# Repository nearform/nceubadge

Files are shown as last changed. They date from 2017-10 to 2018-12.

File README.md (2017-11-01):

# NodeConf EU 2017 Badge

Open Source Hardware Board 

### All documentation including the Getting Started Guide and explanations of the sample code in this repo is available on [nodeconfeubadge.org](http://nodeconfeubadge.org)

## Hardware
This is an Open Source Hardware project. Schematics and board design files are available in the /hardware directory

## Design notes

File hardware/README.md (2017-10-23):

Nodeconf EU hardware design files
=================================

The Badge's hardware was designed in [Eagle CAD](https://www.autodesk.com/products/eagle/overview)

You'll find the original design files here, as well as PDF versions of the schematic and board.

Parts
-----

The main components are:

* [MDBT42Q](http://www.raytac.com/download/MDBT42/MDBT42Q%20&%20MDBT42Q-P-Version%20D.pdf) Bluetooth Module (with [nRF52832](https://www.nordicsemi.com/eng/Products/Bluetooth-low-energy/nRF52832) MCU)
* [MCCOG128064B12W-SPR](http://www.farnell.com/datasheets/2151561.pdf) LCD

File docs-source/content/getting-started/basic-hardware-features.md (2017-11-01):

---
title: "Accessing Hardware Features"
weight: 8
date: 2017-10-28T15:30:33+01:00
draft: false
---

This is an Open Source Hardware project. Schematics and board design files are available in the [/hardware directory of the repo](https://github.com/nearform/nceubadge/tree/master/hardware).

The badge uses the same core module as the [Puck.js](https://www.espruino.com/Puck.js) and can run most of the same software. 

Hardware Features include:

* nRF52832 SoC - 64MHz ARM Cortex M4, 64kB RAM, 512kB Flash, running the Espruino stack
* Bluetooth Low Energy
* Powered by a CR2032 battery which can last up to a week depending on what code you are running
* Daylight-readable LCD screen
* 6 input buttons
* Capacitive touch sensors on all 6 corners
* Prototyping area with 8 CPU pins accessible
* Holes for LEDs on all 6 corners
* NFC antenna
* SWD programming pins

### CPU Pins (Vertical line of holes along left hand edge of badge)
You write to or read from a pin with: 

```javascript
digitalWrite(pin, value);
digitalRead(pin);
```

where pin is one of D0, D1, D2, D3, D4, D5, D6, D7, D8 (D0 at top) and value is 0 or 1.

The firmware has some extra API calls and variables for some of the badge features. You can use them as follows:

### Buttons
You can use  

```javascript
digitalWrite(button, value);
digitalRead(button);
``` 

where value is 1 or 0 and button is one of BTNA, BTNB, BTNU, BTND, BTNL, BTNR

### LEDs
If you add LEDs to the corner holes, you can turn them on/off with 

```javascript
digitalWrite(led);
```

where led is one of LED1, LED2, LED3, LED4, LED5, LED6.

### Graphics
In many Espruino examples on the main site, you'll find setup code for different types of screens. That has already been taken care of for you on the badge and you can just access the graphics functions directly. e.g.

```javascript
g.clear();
g.drawString("Hello World",0,0);
g.flip();
``` 

### Capacitive Sense
You can read the capacitance (and hence touch) from the 6 corners using 

```javascript
Badge.capSense(corner);
```

where corner is one of CORNER1, CORNER2, CORNER3, CORNER4, CORNER5, CORNER6. 

### Battery Percentage
You can get an estimate of the battery level by calling 

```javascript
Badge.getBatteryPercentage();
```

It returns an approximate battery percentage remaining based on a normal CR2032 battery (2.8 - 2.2v).

### Set Screen Contrast
You can set the screen contrast with

```javascript
Badge.setContrast(c)
```

where c is a float from 0 to 1

### NFC
You can set the URL that the NFC antenna broadcasts to NFC-capable phones by calling

```javascript
NRF.nfcURL("url")
```

where URL is something like https://www.nearform.com

*NOTE: If your phone is having difficulty picking up the NFC URL, it is likely that the tuning capacitors on your badge need to be changed to different values. Head on over to the Hacking Lounge to get them replaced or be shown how to do it yourself.*

## Advanced: Flashing updated firmware
If you need to flash new firmware to the badge, you must first put it in DFU mode by holding BTNA as you insert the battery and quickly letting go of BTNA. Download the Distribution Packet Zip file containing the new firmware to your phobe and use nRF Toolbox on either [Android](https://play.google.com/store/apps/details?id=no.nordicsemi.android.nrftoolbox&hl=en) or [iOS](https://itunes.apple.com/us/app/nrf-toolbox/id820906058?mt=8) to send it to the badge.

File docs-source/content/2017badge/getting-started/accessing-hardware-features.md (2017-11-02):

---
title: "Accessing Hardware Features"
weight: 8
date: 2017-10-28T15:30:33+01:00
draft: false
---

This is an Open Source Hardware project. Schematics and board design files are available in the [/hardware directory of the repo](https://github.com/nearform/nceubadge/tree/master/hardware).

The badge uses the same core module as the [Puck.js](https://www.espruino.com/Puck.js) and can run most of the same software. 

Hardware Features include:

* nRF52832 SoC - 64MHz ARM Cortex M4, 64kB RAM, 512kB Flash, running the Espruino stack
* Bluetooth Low Energy
* Powered by a CR2032 battery which can last up to a week depending on what code you are running
* Daylight-readable LCD screen
* 6 input buttons
* Capacitive touch sensors on all 6 corners
* Digital I/O on all 6 corners
* Analogue-in on 3 corners
* Prototyping area with 8 CPU pins accessible
* Digital I/O on all 8 pins
* Analogue-in on 4 pins
* Holes for LEDs on all 6 corners
* NFC antenna
* SWD programming pins

### Proto holes and corner holes
You write or read a digital high/low to/from a hole with: 

```javascript
digitalWrite(hole, value);
digitalRead(hole);
```

where hole is one of D0, D1, D2, D3, D4, D5, D6, D7, D8 (D0 at top), CORNER1, CORNER2, CORNER3, CORNER4, CORNER5, CORNER6 and value is 0 or 1.

You read an analogue value from a hole with: 

```javascript
analogRead(hole);
```

where hole is one of D2, D3, D4, D5, CORNER4, CORNER5, CORNER6.

### Buttons
You can use a generic call like 

```javascript
digitalRead(button);
``` 

where button is one of BTNA, BTNB, BTNU, BTND, BTNL, BTNR

or with a Button-specific call 

```javascript
BTNx.read();
``` 

where BTNx is one of BTNA, BTNB, BTNU, BTND, BTNL, BTNR

### LEDs
If you add LEDs to the corner holes, you can turn them on/off with a generic call

```javascript
digitalWrite(led, value);
```

where led is one of LED1, LED2, LED3, LED4, LED5, LED6.

or with an LED-specific call 

```javascript
LEDx.write(value);
```

where LEDx is one of LED1, LED2, LED3, LED4, LED5, LED6 and value is 0 or 1.

### Graphics
In many Espruino examples on the main site, you'll find setup code for different types of screens. That has already been taken care of for you on the badge and you can just access the graphics functions directly. e.g.

```javascript
g.clear();
g.drawString("Hello World",0,0);
g.flip();
``` 

### Capacitive Sense
You can read the capacitance (and hence touch) from the 6 corners using 

```javascript
Badge.capSense(corner);
```

where corner is one of CORNER1, CORNER2, CORNER3, CORNER4, CORNER5, CORNER6. See [note here](/getting-started/using-prototyping-area/#important-note-re-leds-and-touch-sensing) about issue of using sense and LEDs together.

### Battery Percentage
You can get an estimate of the battery level by calling 

```javascript
Badge.getBatteryPercentage();
```

It returns an approximate battery percentage remaining based on a normal CR2032 battery (2.8 - 2.2v).

### Set Screen Contrast
You can set the screen contrast with

```javascript
Badge.setContrast(c)
```

where c is a float from 0 to 1

### NFC
You can set the URL that the NFC antenna broadcasts to NFC-capable phones by calling

```javascript
NRF.nfcURL("url")
```

where URL is something like https://www.nearform.com

## Advanced Only: Flashing updated firmware
If you need to flash new firmware to the badge, you must first put it in DFU mode by holding BTNA as you insert the battery and quickly letting go of BTNA. Download the Distribution Packet Zip file containing the new firmware to your phone and use nRF Toolbox on either [Android](https://play.google.com/store/apps/details?id=no.nordicsemi.android.nrftoolbox&hl=en) or [iOS](https://itunes.apple.com/us/app/nrf-toolbox/id820906058?mt=8) to send it to the badge.

Please only do this if you are sure you need it. By using a stock badge build from the Espruino site, you'll lose the built-in NodeConf EU main.js code and will just have a REPL over Bluetooth on your badge.

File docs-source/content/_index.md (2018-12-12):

# The NodeConf EU 2018 Badge

Welcome!

We hope you are as excited as we are about the badge. We've spent the past few months designing and preparing it for the event.

The blog post announcing the badge is [here](https://www.nearform.com/blog/the-nodeconf-eu-2018-digital-badge-is-here-and-its-fabulous/).

## The Badge

The badge contains a small but powerful Bluetooth LE module running [Espruino](https://www.espruino.com) software, which is a JavaScript interpreter optimised for low-power devices. On this site, we'll explain the basics of using and programming the badge and even how to add hardware to it.

Note that all of the software and hardware for this year's badge will be Open Sourced shortly after NodeConf EU 2018 is over.

## Changing your name on the badge

This was the top request during NodeConf EU so we've made it as easy as possible. Just [go here](https://nearform.github.io/nceubadge2018/namechanger.html) and follow the simple instructions.

## Quick Links

- [GitHub Repo](https://github.com/nearform/nceubadge2018)
- [Espruino Bluetooth Getting Started](http://www.espruino.com/Quick+Start+BLE#pixljs)
- [Espruino Pixl.js info](http://www.espruino.com/Pixl.js)
- [Monday's Bluetooth Workshop](https://gfwilliams.github.io/workshop-nodeconfeu2018/)
- [Returning your badge to normal](#returning-to-standard)
- [The Badge's default firmware](https://github.com/nearform/nceubadge2018/blob/master/js/badge.js)

Please submit PRs for any apps or backlight patterns you created in:

- [Apps](https://github.com/nearform/nceubadge2018/tree/master/apps)
- [Patterns](https://github.com/nearform/nceubadge2018/tree/master/patterns)

To add them to your badge, connect with the IDE then copy and paste
them into the left-hand side of the IDE.

## Getting Started

The badge is based on a [Pixl.js](http://www.espruino.com/Pixl.js), so a
lot of the tutorials and information there still apply.

The button names can be hard to read because of the badge surround, but they
are as follows:

```
  ......                      ......
      ___________________________
BTN1 |                           | BTN2
     |                           |
     |                           |
     |                           |
BTN4 |___________________________| BTN3
                  ::::
```

There is an on/off slider switch on th rear of the badge just by the USB connector
(which is used for charging only).

## Bugs!

- On some of the badges, the vibration caused by the vibration motors during startup can
  cause the LED controller to stop working. If when you power your badge on it _doesn't_ go
  through all the colours of the rainbow, power it on with your thumbs over the vibration motors
  at the bottom left and right of the screen.
- If your badge stops animating while in badge mode, try just pressing a button
  and it should spring back to life (updating the actual Espruino firmware can fix
  this - see [Updating Espruino](#updating-espruino) below).
- When you charge the badge via USB, the on/off switch on the back needs to be
  set to ON (with the sticky-out part nearest the USB connector) or the battery
  won't charge.
- If you're writing bits of code using `require("Storage").write('.boot...')`
  you may eventually get errors about not being able to write (the same can happen
  when trying to change settings). You can solve this by following the
  [Returning your badge to normal](#returning-to-standard) instructions -
  but [Updating Espruino](#updating-espruino) can stop it happening again as well.

## Connecting

To avoid a complete free-for-all, when the badges start with the Nodeconf badge software
they disable the ability to connect to them. To connect, you must do one of:

- Go to the `Make Connectable` menu item
- Power the badge off, and power it on with `BTN2` or `BTN3` held down. The badge
  firmware will be loaded, but your badge will be connectable.
- (Not recommended) Power the badge off, and power it on with `BTN1` held down while the bootloader
  percent bar goes to the end, **then release when told. Do not keep holding the button
  down or all saved badge code will be erased.**. This initialises a self
  test, which will fail (because the board isn't quite a standard Pixl.js). This
  will start your badge without loading any of the badge code.

You can then use the Chrome web Browser on any Windows 10 or Mac OS device
and go to <a href="https://www.espruino.com/ide" target="_blank">espruino.com/ide</a> and you can connect.
You're looking for a device called `Pixl abcd` where `abcd` are the last 4
characters of the MAC address shown on the Badge's screen.

\*If you used Espruino before, ensure that the `Save on Send` option in the
`Communications` part of the Web IDE's settings is set to `To RAM` otherwise
you'll overwrite the badge firmware.\*\*

Check out the notes for Monday's [Bluetooth Workshop](https://gfwilliams.github.io/workshop-nodeconfeu2018/)
for more information.

### Using your own Editor

You can use the Espruino CLI:

```
npm install -g espruino

# abcd = last 4 digits displayed on your badge
espruino -d abcd --config RESET_BEFORE_SEND=false -w filename.js
```

The `-w filename,js` option watches that file for changes, so the connection
to the badge (and REPL) will be maintained and every time you save the file
in your editor it'll automatically upload.

In this case the CLI tool will upload to RAM without resetting the device,
so writing an app like this will allow you to quickly test your code:

```
Badge.apps["My App"] = ()=>{
 // Reset everything on the badge to a known state
 Badge.reset();
 // Display a menu
 Pixl.menu({ "": { "title": "-- A Test --" },
   "LED1 on" : ()=>LED1.write(1),
   "LED1 off" : ()=>LED1.write(0),
   "Back to Badge":Badge.badge
  });
};
// automatically run app for testing
Badge.apps["My App"]();
```

## Returning to Standard

- <a href="https://www.espruino.com/ide/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" target="_blank">Click this link</a> in Chrome
- Change `Badge.NAME = ...` to `["Your", "Name"]` - each array element is a new line
- Connect to your badge (see above)
- If you're having trouble connecting, power your badge on with `BTN1` held down for ~10 seconds (until a message about code being erased is shown) - this will remove all code from the badge and make it connectable - ready for you to re-upload the badge code.
- Optional: Type `require("Storage").eraseAll()` in the left hand side of the IDE. This will remove all data from nonvolatile storage.
- Turn the `Save on Send` option in the `Communications` part of the Web IDE's settings to `Direct To Flash`
- Upload the code
- Return the `Save on Send` option in the `Communications` part of the Web IDE's settings to `To RAM` so you don't accidentally overwrite the code in the future.

You're sorted!

## Stuff to do

On the badge, you have a bunch of stuff you can use. Most of it is available via `NC`
in a global variable created by the badge software. If you're trying to
do things on your own without the badge software, use `var NC = require("nodeconfeu2018");`
first.

### Bluetooth

Check out [the Pixl.js page](http://www.espruino.com/Pixl.js) for examples.

### LED1, LED2

You can turn the LEDs on and off with `digitalWrite(LED1,1)` or `LED1.write(1)`. Use `0` to turn them off.

### RGB lighting

The badge has fancy RGB lighting. There's:

- **LEDs facing up** - Change these with `NC.ledTop([R,G,B])` or `NC.ledTop([])` to turn them off
- **LEDs facing down** - Change these with `NC.ledBottom([R,G,B])` or `NC.ledBottom([])` to turn them off
- **LCD backlight with 4 zones** - Change this with `NC.backlight([B,G,R,B,G,R,B,G,R,B,G,R])` or `NC.backlight([])` to turn them off

In the above code, `B/G/R` are numbers between 0 and 255 and represent Blue, Green and Red.

### Light sensor

LED2 can be used as an ambient light sensor - just use `NC.light()` to get
a reading between 0 and 1.

It will _definitely_ be thrown off by any light from any of the other on-badge LEDs.

### Vibration

You can use the vibration motors just like normal pins on Espruino...

```
// Use VIBL/VIBR for left and right motors

// Motor on
digitalWrite(VIBL,1);
// Motor off
digitalWrite(VIBL,0);
// Pulse motor on for 100ms
digitalPulse(VIBL,1,100);
// Pulse motor 3 times, for 100ms, with 150ms between each pulse
digitalPulse(VIBL,1,[100,150,100,150,100]);

// Or slowly ramp the speed of the motor up and down
var n = 0;
setTimeout(function cb() {
  analogWrite(VIBL,Math.sin(n));
  n+=0.01;
  if (n<Math.PI) setTimeout(cb,20);
  else digitalWrite(VIBL,0);
}, 20);
```

### Sound

The vibration motors can also be used to create (reasonably quiet) sounds.

```
analogWrite(VIBL,0.05,{freq:2000});  // Make sound!
```

There are some very simple examples at http://www.espruino.com/Making+Music
that will work on the vibration motor - just make sure that the second argument
of `analogWrite` (the duty cycle) is low enough that the vibration motor isn't
turning!

### Accelerometer

```
console.log(NC.accel());
// {x,y,z}
```

### Magnetometer

```
console.log(NC.mag());
// {x,y,z}
```

### LiPo

```
NC.getBatteryState()
// { charging:bool, standby:bool}
```

## Extending the badge

You can add your own 'Apps' or LED patterns that will display in the Badge's
memory just by adding them to the `Badge.patterns` or `Badge.apps` arrays.

Normally when you upload code from the right-hand side of the IDE it will reset
the badge (this won't remove saved code, but will stop the badge code from running).
To avoid this, either copy/paste your code from the right-hand side of the IDE
to the left, or disable the `Reset before send` option in the `Communications` part
of the Web IDE's settings.

## Patterns

Just do something like:

```
// LED patterns - each is [callback, period_in_ms]
Badge.patterns.blue=()=>{ var n=0;return [()=>{
  var c = [127,0,0];
  NC.ledTop(c);
  NC.ledBottom(c);
  NC.backlight(c.concat(c,c,c));
},0];};
```

And you can test by running `Badge.pattern("mine")`.

The above example will only be called once because it returns `0` for `period_in_ms`,
but you can easily supply a different value to be called more often:

```
Badge.patterns.green=()=>{ var n=0;return [()=>{
  n+=50;
  if (n>1536)n=0;
  NC.ledTop([0,Math.max(255-Math.abs(n-1024),0),0]);
  NC.ledBottom([0,Math.max(255-Math.abs(n-1384),0),0]);
  NC.backlight([0,Math.max(255-Math.abs(n-640),0),0,
                0,Math.max(255-Math.abs(n-512),0),0,
                0,Math.max(255-Math.abs(n-384),0),0,
                0,Math.max(255-Math.abs(n-256),0),0]);
},50];};
```

50ms is usually a good balance of battery life and smoothness.

## Apps

Just write your app to the `Badge.apps` array:

```
Badge.apps["My App"] = ()=>{
 // Reset everything on the badge to a known state
 Badge.reset();
 // Display a menu
 Pixl.menu({ "": { "title": "-- A Test --" },
   "LED1 on" : ()=>LED1.write(1),
   "LED1 off" : ()=>LED1.write(0),
   "Back to Badge":Badge.badge
  });
};
```

And you can test by running `Badge.apps["My App"]()`

To return to normal badge functionality just call `Badge.badge()` or `Badge.menu()`
to return to the menu.

## Saving...

When you upload code as described above, your function will be loaded
into RAM and will be lost when the badge is reset.

To make it persist, you can write it into a file in the badge's storage
called `.boot0`,`.boot1`,`.boot2` or `.boot3` - each one is executed in
turn on boot so you can have more than one extension at once.

```
require("Storage").write(".boot0",`
Badge=global.Badge||{};
Badge.apps=Badge.apps||{};
Badge.apps["My App"] = ()=>{
 // Reset everything on the badge to a known state
 Badge.reset();
 // Display a menu
 Pixl.menu({ "": { "title": "-- A Test --" },
   "LED1 on" : ()=>LED1.write(1),
   "LED1 off" : ()=>LED1.write(0),
   "Back to Badge":Badge.badge
  });
};
`);
```

You can also do things like overwrite the built-in name,
without having to overwrite the basic badge firmware.

```
require("Storage").write(".boot1",`
Badge=global.Badge||{};
Badge.NAME=["Hello","World"];
`);
```

## Common Pitfalls

- If you get `Badge not found` errors while trying to upload an app from the right hand side, it'll be because you're uploading with the `Reset before send` option turned on in the IDE settings (it should be turned off)
- `reset()` (or 'reset before send) removes all JS code from the badge's RAM (including the `Badge` object) - it can be handy if you want to have full control of everything on the badge. To get back, see the next point...
- If you want to get your badge firmware back out of flash memory _without_ power cycling your badge, just type `load()` in the left-hand side of the IDE
- Calling `Badge.menu()` will bring the Badge's menu back up - `Badge.badge()` goes back to displaying the badge. If you want a button in the app to bring you back to the menu, you can just call: `setWatch(Badge.menu, BTN1);`
- `Badge.reset()` attempts to reset the badge's state (removing watches and intervals) - it's an idea to stick this as the first line in your app to make sure you start from a known state each time.

## Soldering Stuff

There are some special GPIO connectors on the badge. These can be accessed with
commands like `digitalWrite(D10,1)` or `analogRead(A0)`.

- `J2` (Top Left) contains (left to right) `GND`,`D10`,`D11`,`D12`,`D13` and `3.3v`
- `J1` (Top Right) contains (left to right) `GND`,`A0`,`A1`,`A2`,`A3` and `3.3v`
- `J3` (Bottom center) contains the pinout for an ESP8266 ESP01 module. This can
  also be used for wired serial comms with the badge:

```
GND            NC    NC        D1(Badge TX)
D0(Badge RX)   D9    NC        3.3v
```

### ESP8266 Wiring

Due to a slight mirroring accident, a normal ESP8266 module has to be attached
to the FRONT of the badge, slightly covering the display:

```
  ......                      ......
      ___________________________
BTN1 |                           | BTN2
     |                           |
     |            ____           |
     |           |    |          |
BTN4 |___________|    |__________| BTN3
                 |::::|
                  ----
```

However by removing the ESP01's pins and soldering them on the other side of the
module, you can fit the ESP01 to the rear of the badge very tidily.

Once soldered you can access the internet as follows:

```
var WIFI_NAME = "...";
var WIFI_PASS = "...";
D9.set(); // power on
Serial1.setup(115200,{rx:D0,tx:D1});
var wifi = require("ESP8266WiFi_0v25").connect(Serial1, function(err) {
  if (err) throw err;
  console.log("Connecting to WiFi");
  wifi.connect(WIFI_NAME, WIFI_PASS, function(err) {
    if (err) throw err;
    console.log("Connected");
    // Now you can do something, like an HTTP request
    require("http").get("http://www.pur3.co.uk/hello.txt", function(res) {
      console.log("Response: ",res);
      res.on('data', function(d) {
        console.log("--->"+d);
      });
    });
  });
});
```

Check out [http://www.espruino.com/Internet](Espruino's page on Internet stuff)
for more info.

## Updating Espruino

The badges came with Espruino v2.00, but there have [been a few changes](https://github.com/espruino/Espruino/blob/master/ChangeLog)
to Espruino since then that have fixed:

- The badge pausing issue (caused by high Bluetooth LE traffic when scanning)
- Filesystem issues when repeatedly calling `require("Storage").write`
- Other issues

To update Espruino, just [follow the Pixl.js instructions here](http://www.espruino.com/Pixl.js#firmware-updates)
with the 'Cutting edge' build linked from [the firmware download page](http://www.espruino.com/Download#pixljs).

This'll take a few minutes, and you then need to follow the steps for [Returning your badge to normal](#returning-to-standard) - so if you're fine with everything as it is, we'd recommend that you keep version 2.00 for now.

## Changing your name on the badge in the Web IDE

This was the top request during NodeConf EU so we've made it as easy as possible. To update the name displayed by the badge, do the following:

- On the badge, press the top left button, then select "Make Connectable" from the menu and note the last four hex digits of the address of the badge
- <a href="https://www.espruino.com/ide/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" target="_blank">Click this link</a> in Chrome to open the Online IDE with the correct code
- In that code, edit the two fields "Bob" and "Loblaw" to whatever you need.
- Click the yellow Connect button in the top left corner of the IDE
- Click "Web Bluetooth" in the pop-up
- Click your device name
- Once connected, click the "Send to Espruino" button in the middle of the IDE
- Reboot your badge and you'll see the new name

## 2017 Badge

The old docs for the 2017 badge can be found in [Getting Started](/2017badge/getting-started/) and [challenges](/2017badge/challenges/).

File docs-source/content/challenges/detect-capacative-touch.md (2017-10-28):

---
title: "Detect Capacitive Touch"
weight: 3
date: 2017-10-28T10:29:15+01:00
draft: false
---
### Challenge 3

Detect the application and removal of your hand from the capacative sensors on the corners of the badge.

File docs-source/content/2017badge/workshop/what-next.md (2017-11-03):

---
title: "What next?"
weight: 9
date: 2017-11-03T09:45:33+01:00
draft: false
---

What about:

* Putting LEDs around the corners and using those to show the correct 
patterns. However, due to the way the capacitive sense and LEDs are shared,
you'll only be able to use White and Blue LEDs, not any of the coloured
ones!
* Getting rid of all the callbacks. I've been super lazy - you could probably
tidy things up a lot more using Promises.
* Make a much better game.
* Use the Bluetooth to connect to another Badge and control it
* Interface with a Web Bluetooth Website
* Make a multiplayer game!

## Other info

There's loads of info to help online.. Check out:

* http://nodeconfeubadge.org/challenges/
* The Puck.js tutorials - the badge is basically a Puck.js: http://www.espruino.com/Puck.js#tutorials
* The search box on the Espruino site: http://www.espruino.com/Search
* The Espruino function reference: http://www.espruino.com/Reference
* All the rest of Espruino's tutorials - http://www.espruino.com/Tutorials
* The forum! http://forum.espruino.com/ (it's also sometimes worth
Googling `site:forum.espruino.com your_search_term` as the forum's
search isn't the best).

## Bluetooth

We didn't cover Bluetooth at all here! There's a super-quick intro to
BLE on Espruino here: http://www.espruino.com/About+Bluetooth+LE

And there's a tutorial on how to get up and running with Web Bluetooth
and Espruino here: http://www.espruino.com/Puck.js+Web+Bluetooth

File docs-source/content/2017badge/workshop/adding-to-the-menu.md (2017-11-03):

---
title: "Adding to your Badge's menu"
weight: 10
date: 2017-11-03T09:45:33+01:00
draft: false
---

Next we're going to add the game we just made as a menu item inside
the existing badge software.

Wrap everything you've done into the following function on the right-hand
side of the IDE.

```
Badge.apps["Simon Game"] = function() {
  Badge.reset();
  setWatch(Badge.menu, BTNB, { repeat: 1, debounce: 50, edge: "rising" });
  
  // Your code
};
```

Now we need to get the badge back doing badgey stuff. disconnect the IDE 
from your badge, and pull the battery gently away from the PCB with a 
fingernail. When the display flickers off, let go and your badge will 
restart with the old code on it.

Now do the Konami code again - `UUDDLRLRBA`, go to `Make Connectable`,
and connect with the Web IDE. Simply **Copy & Paste** your code from the
right-hand side over to the left, **don't Upload**. If you upload, it'll
reset the device and upload your code as it did before.

This way, your code will now be loaded into RAM alongside the Badge's code.

Disconnect the IDE and press the `A` button on the badge to exit the
`Connectable` state. You'll now have a new menu item at the end of the list 
called `Simon Game`, and when you choose it it'll run your game!

**Note:** We've totally filled up the flash memory with all the Badge stuff,
so you won't be able to save your game like this and if you reset your badge
by removing the battery it'll disappear.

Instead, you'd have to upload and save just the game as was done in the
last step.

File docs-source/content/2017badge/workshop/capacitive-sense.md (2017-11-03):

---
title: "Capacitive Sense"
weight: 3
date: 2017-11-03T09:45:33+01:00
draft: false
---

To detect a press, we want to use the capacitive sense functionality on the badge.
Type `Badge.capSense(1)` on the left-hand side of the IDE. You can use tab-complete
to help you. You should get a number displayed in the region of about `10,000` - this
value depends on the capacitance on that corner of the badge.

Press your finger on the corner marked `1` and try again (up arrow, then enter)
- you should see a much higher value - probably over `100,000`.

We can read all 6 corners using ES6 arrow functions and `map`:

```
[1,2,3,4,5,6].map(c=>Badge.capSense(c))
```

Note that not all corners are identical - for instance the corner nearest the
Bluetooth module (corner 3) will probably read a bit less, because there's less
wire.

It's easy enough for us to just threshold the capacitance values to
return an array of boolean values. You can use up-arrow and left to
move the cursor and edit the last line (or even the mouse), **but
you need to get the cursor on the end of the line before you
hit enter or it'll create a newline rather than executing**:

```
[1,2,3,4,5,6].map(c=>Badge.capSense(c)>20000)
```

So at this point it'd be nice to use the display to show our values...

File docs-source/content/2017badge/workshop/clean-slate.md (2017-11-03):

---
title: "Clean Slate"
weight: 2
date: 2017-11-03T09:45:33+01:00
draft: false
---

Clear everything out of the right-hand side of the IDE window, and click the
'Upload' button in the middle of the screen (a picture of a chip and an up-arrow).

The Badge should now just display the 'Espruino' logo - this is what gets
displayed when no code has been loaded.

Don't worry though **- this hasn't overwritten what was on the badge before.**
That code is in Flash memory, and uploading an empty file has left the contents
 of RAM empty, while the Flash memory has stayed the same. Removing the battery
 and re-inserting (or flicking it away with your finger) will make the badge
 reload everything.

**Note:** If you have `Save on Send` set in the options, or type `save()`
then it *will* blow away the contents of the badge.

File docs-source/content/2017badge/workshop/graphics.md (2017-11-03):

---
title: "Graphics"
weight: 4
date: 2017-11-03T09:45:33+01:00
draft: false
---

The badge exposes the LCD via a built-in variable called `g`. This has 
a bunch of methods such as `drawLine` or `drawString` that can be accessed
(http://www.espruino.com/Graphics) however each command acts on an internal
memory buffer. To update the display itself you need to call `g.flip()`.

Try entering the following code on the left-hand side:

```
g.clear();
g.drawString("Hello World!");
g.flip();
```

The badge should now display the obvious 'Hello World'!

But what if we want to display our capacitance data? Enter the following
on the *left-hand side*.

```
function plotCap() {
  g.clear();  
  var caps = [1,2,3,4,5,6].map(c=>Badge.capSense(c));
  caps.forEach(
    (cap,x) => g.fillRect(x*21,64,(x+1)*21, 64-cap/1000)
  );
  g.flip();
}
setInterval(plotCap,50)
```

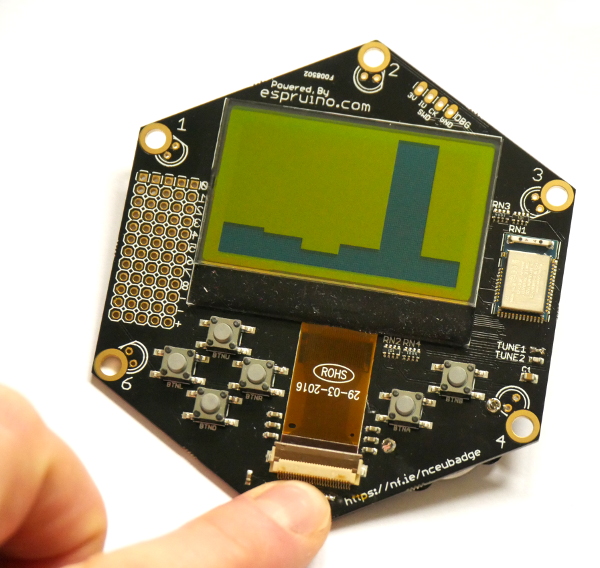
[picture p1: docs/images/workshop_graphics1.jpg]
Plot capacitance


**Note:** This uses a whole bunch of battery power because of polling the
capacitive sense as well as updating the screen, and if left this way
could run the Badge's battery down in a few hours. When using the buttons
rather than capacitive sense, the hardware itself can detect the change
in the wire's voltage while the processor is asleep - you do that
using `setWatch` - which is super power efficient.

This is just displaying a few bars, but it would make more sense to display
the status on a hexagon that matched the badge itself:

```
function plotBadge(presses) {
  g.clear();    
  // function to work out each corner's coordinates
  function corner(c,r) {
    var a = (c-2)*Math.PI/3;
    return [64+Math.sin(a)*40*r, 32-Math.cos(a)*30*r];
  }
  // draw a hexagon - a line to each corner in turn
  g.moveTo.apply(g,corner(6,1));
  [1,2,3,4,5,6].forEach(c=>g.lineTo.apply(g,corner(c,1)));
  // Draw a circle where pressed
  presses.forEach((hit,c) => {
    if (!hit) return;
    var coords = corner(c+1,0.8);
    g.fillCircle(coords[0],coords[1],5);
  });
  g.flip();
}

function plotCap() {  
  var caps = [1,2,3,4,5,6].map(c=>Badge.capSense(c)>20000);
  plotBadge(caps);
}
```

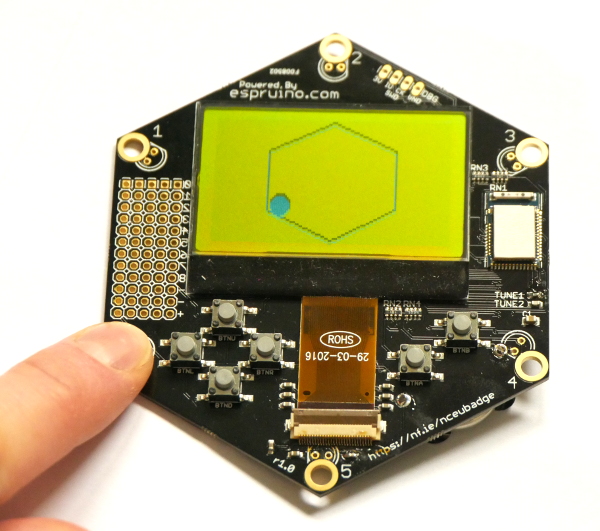
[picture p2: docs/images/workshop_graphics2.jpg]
Plot corners


We're using a separate `plotBadge` function here so we can use it
later to output the pattern we want the user to enter.

**Note:** because we're entering this on the left-hand side we
already have the interval from the last code we entered - just
re-entering `plotCap` will replace the old one and the code will magically
start working.

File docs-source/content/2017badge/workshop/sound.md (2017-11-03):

---
title: "Sound"
weight: 5
date: 2017-11-03T09:45:33+01:00
draft: false
---

It'd be nice if our game made some sounds. There's no speaker built into the
badge, so we're going to add one.

Get one of the gold coloured discs from the hacking bench - these are piezo
speakers of the type you'd find in digital watches.

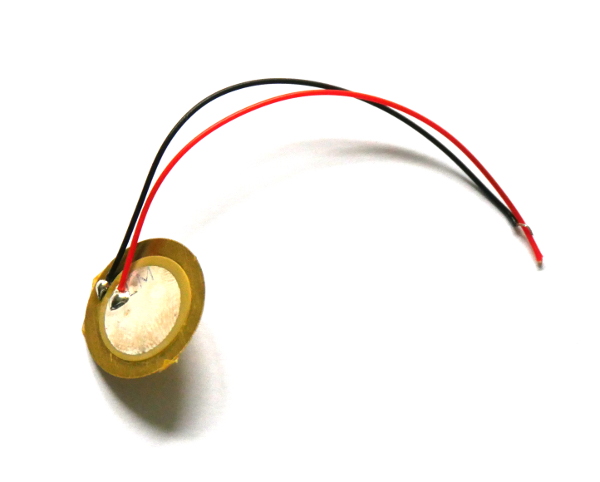
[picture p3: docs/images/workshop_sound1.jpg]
Piezo


Use the wire strippers and try and strip around 2cm of insulation off each of
the two wires. By careful - maybe try stripping 1cm first, then another cm,
as the wire is really delicate.

Twist each bit of wire so it makes a nice braid, then poke each through the
holes on the edge of the board marked 0 and 1 (the order doesn't matter) and
twist them around tightly as below. 0 and 1 correspond to pins `D0` and `D1`.

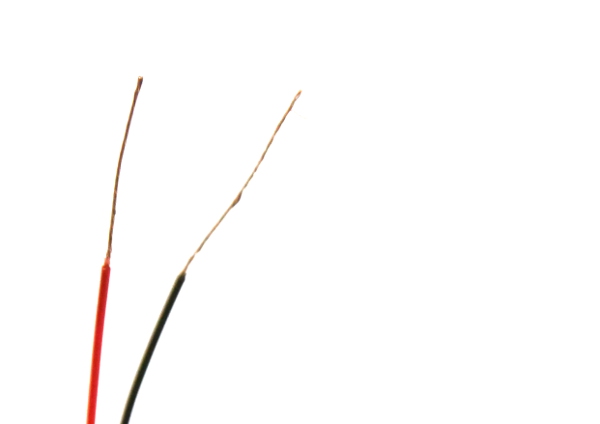
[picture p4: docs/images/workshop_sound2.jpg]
Piezo wires


**Note:** You're welcome to solder the speaker on if you want to - it's just
quick and reversible to twist.

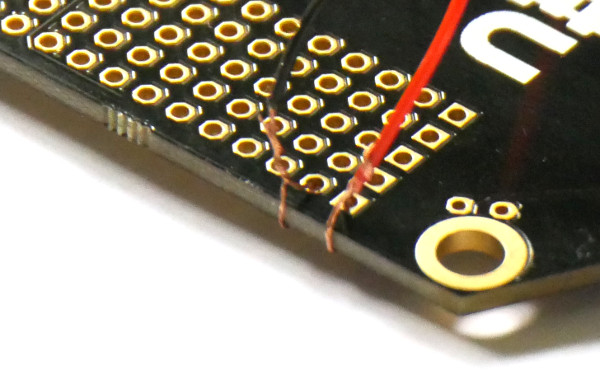
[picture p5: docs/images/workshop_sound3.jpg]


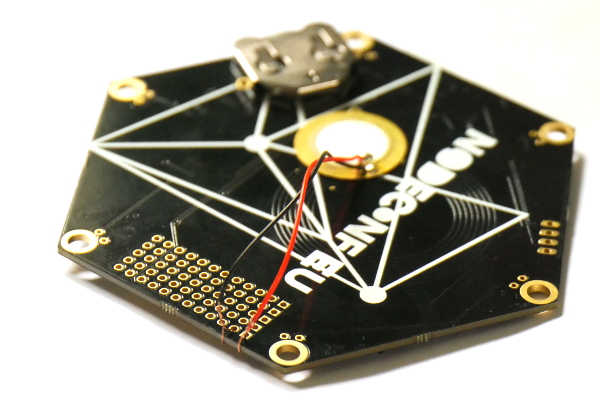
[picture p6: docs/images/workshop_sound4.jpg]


Now get a bit of double-sided tape and tape the speaker to the back of your 
badge. It makes it louder if it can vibrate something else.

Now you can test it - in the left-hand side of the IDE type:

```
digitalWrite(D0,0)
```

This sets pin `D0` to be connected to ground.

```
analogWrite(D1,0.5,{freq:1000})
```

This puts a 1kHz frequency on pin D1, and you should be able to hear
a really annoying high pitched beep.

Type this to turn it off:

```
digitalWrite(D1,0)
```

So now all we need is a handy function to do timed beeps:

```
function beep(freq, time, callback) {
  digitalWrite(D0,0);
  analogWrite(D1,0.5,{freq:freq});
  setTimeout(function() {
    digitalWrite(D1,0);
    if (callback) callback();
  }, time);
}
```

Which you can try with:

```
beep(700,1000)
```

For a 700Hz beep for 1 second, and so on...

For our Simon game we need a different beep for each corner, so let's make
a function for that.

```
function beepForCorner(corner, time) {
  var pitches = ["no_corner_0",
    500,
    600,
    700,
    800,
    900,
    1000
  ];
  beep(pitches[corner], time);
}
```

Which you can use with `beepForCorner(2,1000)`.

These pitches are totally un-musical, but if you were so inclined you could
look up some more pleasing notes at https://pages.mtu.edu/~suits/notefreqs.html
and use those frequencies instead.

## It's too quiet!

(optional!)

Unfortunately the piezo speakers we're using aren't really meant to run
off a voltage as low as we have on the badge (3V).

We're driving them with a square wave between 0V and 3V while `D0` is at 0V, 
so the total swing in voltage is 0V.

However, if we could make `D0` go to 3V when `D1` was at 0V and vice-versa,
we'd be able to get double the voltage swing - 6V!

The following code uses the NRF52LL library, which has a bit more info
in it: http://www.espruino.com/NRF52LL

Basically there's nothing built in to the Espruino interpreter to handle this,
so we have to set up the hardware that's on the chip ourself - which is
pretty low-level.

```

function beep(freq, time, callback) {
  var ll = require("NRF52LL");
  // set up D0 and D1 as outputs
  digitalWrite(D0,0);
  digitalWrite(D1,0);
  // create two 'toggle' tasks, one for each pin
  var t0 = ll.gpiote(6, {type:"task",pin:D0,lo2hi:1,hi2lo:1,initialState:0});
  var t1 = ll.gpiote(7, {type:"task",pin:D1,lo2hi:1,hi2lo:1,initialState:1});
  // create a timer that counts up to a value depending on the frequency
  var tmr = ll.timer(3,{cc:[500000/freq],cc0clear:1});
  // use two PPI to trigger toggle events
  ll.ppiEnable(6, tmr.eCompare[0], t0.tOut);
  ll.ppiEnable(7, tmr.eCompare[0], t1.tOut);
  // Manually trigger a task to start the timer
  poke32(tmr.tClear,1);
  poke32(tmr.tStart,1);
  setTimeout(function() {
    poke32(tmr.tStop,1);
    ll.ppiDisable(6);
    ll.ppiDisable(7);
    if (callback) callback();
  }, time);
}
```

This code uses a library that's dynamically loaded in by the IDE, so you'll
have to use the code on the **right-hand side of the IDE** and use the `Upload` button
in order to have it work correctly.

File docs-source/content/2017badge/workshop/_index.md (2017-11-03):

---
title: "Workshop"
weight: 3
chapter: true
date: 2017-11-02T10:29:15+01:00
draft: false
---

# Monday's Workshop

We're going to make a 6-cornered ['Simon' game](https://en.wikipedia.org/wiki/Simon_(game)),
 using capacitive sense on each corner of the badge instead of the usual 4 cornered game.

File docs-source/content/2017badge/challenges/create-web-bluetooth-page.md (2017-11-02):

---
title: "Create a Web Bluetooth Page"
weight: 12
date: 2017-10-28T10:29:15+01:00
draft: false
---
### Challenge 12

Implement a webpage that uses Web Bluetooth with the Puck.js library. Start simple and turn on/off an LED on your badge.

Eventually make it retrieve your last tweet from the Twitter API and then display it on the badge screen.

Lots of information about web Bluetooth and Espruino [here](https://www.espruino.com/Puck.js+Web+Bluetooth).

#### Add a menu via Web Bluetooth
You can really see the power of Web Bluetooth and Espruino by trying something like this:

```javascript
Puck.write(`
Badge.apps["My Foobar"] = function() {
  Badge.reset();
  // my stuff
  // when done, call Badge.menu
  // eg. setWatch(Badge.menu, BTNB, { repeat: 1, debounce: 50, edge: "rising" });
};
`);
```
Create code based on the above in a webpage and host it on GitHub Pages. Write it so that anyone can go to the page, click a button and add the app to their badge.

Note however that if you use any of Espruino's modules, you'll have to run it through the CLI first to output a JS file that also contains the modules.

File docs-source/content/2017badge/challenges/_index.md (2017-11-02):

---
title: "Challenges"
weight: 2
chapter: true
date: 2017-10-28T10:29:15+01:00
draft: false
---

# Try all of these challenges!
You'll start with Hello World and hopefully by Wednesday you'll have a giant P2P badge network running.

Try combining multiple challenges into one codebase.

1. Hello World on screen
2. Detect Button press
3. Detect capacitive touch
4. Add LEDs and flash them
5. Add a Buzzer/Speaker and play music
6. Implement your own on-screen menu
7. Broadcast a different NFC URL
8. Broadcast an Eddystone and iBeacon message
9. Use Noble and Node.js on your laptop to read the beacon data  
10. Turn the Badge into HID buttons for your PC.
11. Create and display your own images
12. Implement Web Bluetooth with the Puck.js library
13. Detect movement with a PIR sensor
14. Connect to a BLE LED Lightbulb
15. Connect to a BLE LED Strip
16. Communicate with another badge
17. Communicate with some other Bluetooth devices
18. Implement DAT protocol on Espruino

### The Grand Challenge
Don't forget [the grand challenge](/#the-grand-challenge)!

### Advanced tools
There are several mobile apps from Nordic Semiconductor that you may find useful in any challenges that use Bluetooth. nRF toolbox can also be used to update the badges firmware or re-flash a badge that you have messed up.

#### Android
* [nRF Connect](https://play.google.com/store/apps/details?id=no.nordicsemi.android.mcp&hl=en)
* [nRF Toolbox](https://play.google.com/store/apps/details?id=no.nordicsemi.android.nrftoolbox&hl=en)

#### iOS
* [nRF Connect](https://itunes.apple.com/us/app/nrf-connect/id1054362403?mt=8)
* [nRF Toolbox](https://itunes.apple.com/us/app/nrf-toolbox/id820906058?mt=8)

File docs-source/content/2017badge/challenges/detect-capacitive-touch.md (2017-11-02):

---
title: "Detect Capacitive Touch"
weight: 3
date: 2017-10-28T10:29:15+01:00
draft: false
---
### Challenge 3

It's very easy to read a capacitance value from the 6 lanyard holes in the badge. Experiment with the code and how the badge responds to touch. Then come up with a use for it. 

See the [getting started area](/getting-started/basic-hardware-features/) for the relevant API call.

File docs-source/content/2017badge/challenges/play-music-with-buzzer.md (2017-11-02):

---
title: "Play Music with Buzzer"
weight: 5
date: 2017-10-28T10:29:15+01:00
draft: false
---
### Challenge 5

We have lots of buzzers at the Hacking Station. You just have to solder the red wire to one of the D0-D6 holes on the edge of the badge and the black wire to one of the Ground (-) holes.

Then impress everyone with your groovy tunes using the [APIs here](https://www.espruino.com/Making+Music).

Note: Gordon is working on a variation of this that uses two digital pins and doubles the output volume.

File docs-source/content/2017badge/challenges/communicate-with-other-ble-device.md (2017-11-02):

---
title: "Communicate with another Device"
weight: 17
date: 2017-10-28T10:29:15+01:00
draft: false
---
### Challenge 17

If you can get your hands on some other BLE device like a Garmin, Fitbit or Milestone, see if you can figure out the protocol.

If you figure it out, write a blogpost about it!

Some of these devices may require registering on the relevant developer sites. However we may have some other Bluetooth devices on the Hacking Table which are easier to communicate with.

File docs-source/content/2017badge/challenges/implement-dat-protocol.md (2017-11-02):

---
title: "Implement Dat Protocol"
weight: 18
date: 2017-10-28T10:29:15+01:00
draft: false
---
### Challenge 18

We're kidding.

Or are we?

What sort of P2P messaging system could be created by all the badges at the event? Without burning through the battery in 5 minutes.

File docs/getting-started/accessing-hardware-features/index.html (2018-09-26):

> Getting Started > Accessing Hardware Features

# Accessing Hardware Features

This is an Open Source Hardware project. Schematics and board design files are available in the /hardware directory of the repo (https://github.com/nearform/nceubadge/tree/master/hardware).

The badge uses the same core module as the Puck.js (https://www.espruino.com/Puck.js) and can run most of the same software.

Hardware Features include:

- nRF52832 SoC - 64MHz ARM Cortex M4, 64kB RAM, 512kB Flash, running the Espruino stack
- Bluetooth Low Energy
- Powered by a CR2032 battery which can last up to a week depending on what code you are running
- Daylight-readable LCD screen
- 6 input buttons
- Capacitive touch sensors on all 6 corners
- Digital I/O on all 6 corners
- Analogue-in on 3 corners
- Prototyping area with 8 CPU pins accessible
- Digital I/O on all 8 pins
- Analogue-in on 4 pins
- Holes for LEDs on all 6 corners
- NFC antenna
- SWD programming pins

### Proto holes and corner holes

You write or read a digital high/low to/from a hole with:

digitalWrite(hole, value);
digitalRead(hole);

where hole is one of D0, D1, D2, D3, D4, D5, D6, D7, D8 (D0 at top), CORNER1, CORNER2, CORNER3, CORNER4, CORNER5, CORNER6 and value is 0 or 1.

You read an analogue value from a hole with:

analogRead(hole);

where hole is one of D2, D3, D4, D5, CORNER4, CORNER5, CORNER6.

### Buttons

You can use a generic call like

digitalRead(button);

where button is one of BTNA, BTNB, BTNU, BTND, BTNL, BTNR

or with a Button-specific call

BTNx.read();

where BTNx is one of BTNA, BTNB, BTNU, BTND, BTNL, BTNR

### LEDs

If you add LEDs to the corner holes, you can turn them on/off with a generic call

digitalWrite(led, value);

where led is one of LED1, LED2, LED3, LED4, LED5, LED6.

or with an LED-specific call

LEDx.write(value);

where LEDx is one of LED1, LED2, LED3, LED4, LED5, LED6 and value is 0 or 1.

### Graphics

In many Espruino examples on the main site, you’ll find setup code for different types of screens. That has already been taken care of for you on the badge and you can just access the graphics functions directly. e.g.

g.clear();
g.drawString("Hello World",0,0);
g.flip();

### Capacitive Sense

You can read the capacitance (and hence touch) from the 6 corners using

Badge.capSense(corner);

where corner is one of CORNER1, CORNER2, CORNER3, CORNER4, CORNER5, CORNER6. See note here about issue of using sense and LEDs together.

### Battery Percentage

You can get an estimate of the battery level by calling

Badge.getBatteryPercentage();

It returns an approximate battery percentage remaining based on a normal CR2032 battery (2.8 - 2.2v).

### Set Screen Contrast

You can set the screen contrast with

Badge.setContrast(c)

where c is a float from 0 to 1

### NFC

You can set the URL that the NFC antenna broadcasts to NFC-capable phones by calling

NRF.nfcURL("url")

where URL is something like https://www.nearform.com

## Advanced Only: Flashing updated firmware

If you need to flash new firmware to the badge, you must first put it in DFU mode by holding BTNA as you insert the battery and quickly letting go of BTNA. Download the Distribution Packet Zip file containing the new firmware to your phone and use nRF Toolbox on either Android (https://play.google.com/store/apps/details?id=no.nordicsemi.android.nrftoolbox&hl=en) or iOS (https://itunes.apple.com/us/app/nrf-toolbox/id820906058?mt=8) to send it to the badge.

Please only do this if you are sure you need it. By using a stock badge build from the Espruino site, you’ll lose the built-in NodeConf EU main.js code and will just have a REPL over Bluetooth on your badge.

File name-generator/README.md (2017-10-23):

# name-generator

This tool prompts for a NodeConf EU attendee's firstname/lastname and then generates base64 image data for saving on the NCEU badge.

It scales each person's name to make best use of the screen

Copyright nearForm and Conor O'Neill 2017 conor@conoroneill.com
Apache License Version 2.0

Usage (Mac only for the moment):

Install [Node.js](https://nodejs.org/en/download/current/) and then:

```
git clone https://github.com/nearform/nceubadge
cd nceubadge/name-generator

# Mac OS
brew install openssl imagemagick pkg-config cairo libpng jpeg giflib
# Debian/Ubuntu Linux
sudo apt-get install imagemagick pkg-config libcairo2-dev libpng-dev libjpeg-dev libgif-dev

npm install
```

Then run the tool just with

```
node name-generator.js
```

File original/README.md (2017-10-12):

Original Badge Code
=====================

As they come, the badges are flashed with the standard Espruino HEXBADGE 
firmware. *Then* the espruino CLI is used to take a custom HEX file based
on `main.js` which is written it direct to flash.

This is as if `E.setBootCode` was called with the badge's code. The bonus
is that everything can be executed from Flash - freeing up LOADS of RAM.

```
# Install CLI
npm install -g espruino

# create hex file from CLI
espruino --board HEXBADGE main.js -ohex main.hex

# optional flash of hexbadge firmware
nrfjprog --family NRF52 --clockspeed 50000 --program espruino_1v94.159_hexbadge.hex --chiperase --reset
# erase saved code area
nrfjprog --family NRF52 --clockspeed 50000 --erasepage 0x71000-0x76000
# Actually program file
nrfjprog --family NRF52 --clockspeed 50000 --program main.hex --reset
```

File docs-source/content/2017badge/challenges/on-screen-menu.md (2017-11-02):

---
title: "On-Screen Menu"
weight: 6
date: 2017-10-28T10:29:15+01:00
draft: false
---
### Challenge 6

If you implement an on-screen menu with up-down-left-right-select then you could have lots of your challenges on the badge at the same time and demo them to people. Have a look at the [github repo](https://github.com/nearform/nceubadge/) for the sample code. 

#### Add to the existing menu 
You can also try the following: 

* Turn off 'Reset Before Send' in the Web IDE options
* Write your code a bit like this:

```javascript
Badge.apps["My Foobar"] = function() {
  Badge.reset();
  // my stuff
  // when done, call Badge.menu
  // eg. setWatch(Badge.menu, BTNB, { repeat: 1, debounce: 50, edge: "rising" });
};
```

* Upload or copy/paste that code 
* It will appear in the apps list on the badge's menu
* You can't save, but it'll persist until you reset the badge

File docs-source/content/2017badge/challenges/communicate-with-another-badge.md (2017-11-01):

---
title: "Communicate with another Badge"
weight: 16
date: 2017-10-28T10:29:15+01:00
draft: false
---
### Challenge 16

This is another advanced challenge. We recommend starting with the [instructions here](https://www.espruino.com/Puck.js+Controlling+Other+Pucks) and then decide if you want to continue.

Also consider the new [BLE mesh networking standard](http://forum.espruino.com/conversations/308148/) which is currently not supported on Espruino but would make for an impressive community contribution.

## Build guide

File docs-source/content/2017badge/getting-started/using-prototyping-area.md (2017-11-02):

---
title: "Using the prototyping area and corners"
weight: 9
date: 2017-10-28T15:30:33+01:00
draft: false
---

You can add whatever hardware you like to the prototyping area. It's where you'll be connecting extra LEDs, buzzers etc. The column of holes along the board's left edge are connected to pins D0 to D8, Ground and Power. However all of the other holes in that grid are unconnected and can be used to attach your components together.

As always, the [Espruino web-site](https://www.espruino.com/) has lots more info and examples.

## Hole behaviour
The edge holes and the corner holes each have slightly different capabilities.

### Prototype holes

* 0 - Digital I/O Only
* 1 - Digital I/O Only
* 2 - Digital I/O and Analogue-in (ADC)
* 3 - Digital I/O and Analogue-in (ADC)
* 4 - Digital I/O and Analogue-in (ADC)
* 5 - Digital I/O and Analogue-in (ADC)
* 6 - Digital I/O Only
* 7 - Digital I/O and Serial TX
* 8 - Digital I/O and Serial RX
 
### Corner holes

* 1 - Digital I/O Only
* 2 - Digital I/O Only
* 3 - Digital I/O Only
* 4 - Digital I/O and Analogue-in (ADC)
* 5 - Digital I/O and Analogue-in (ADC)
* 6 - Digital I/O and Analogue-in (ADC)

## Important note re LEDs and touch sensing
As LEDn == CORNERn, adding most LEDs to a corner will prevent capacitive sense functioning on that corner. White and blue LEDs will probably work but not other colours.

## Board layout
This shows the basic board layout:

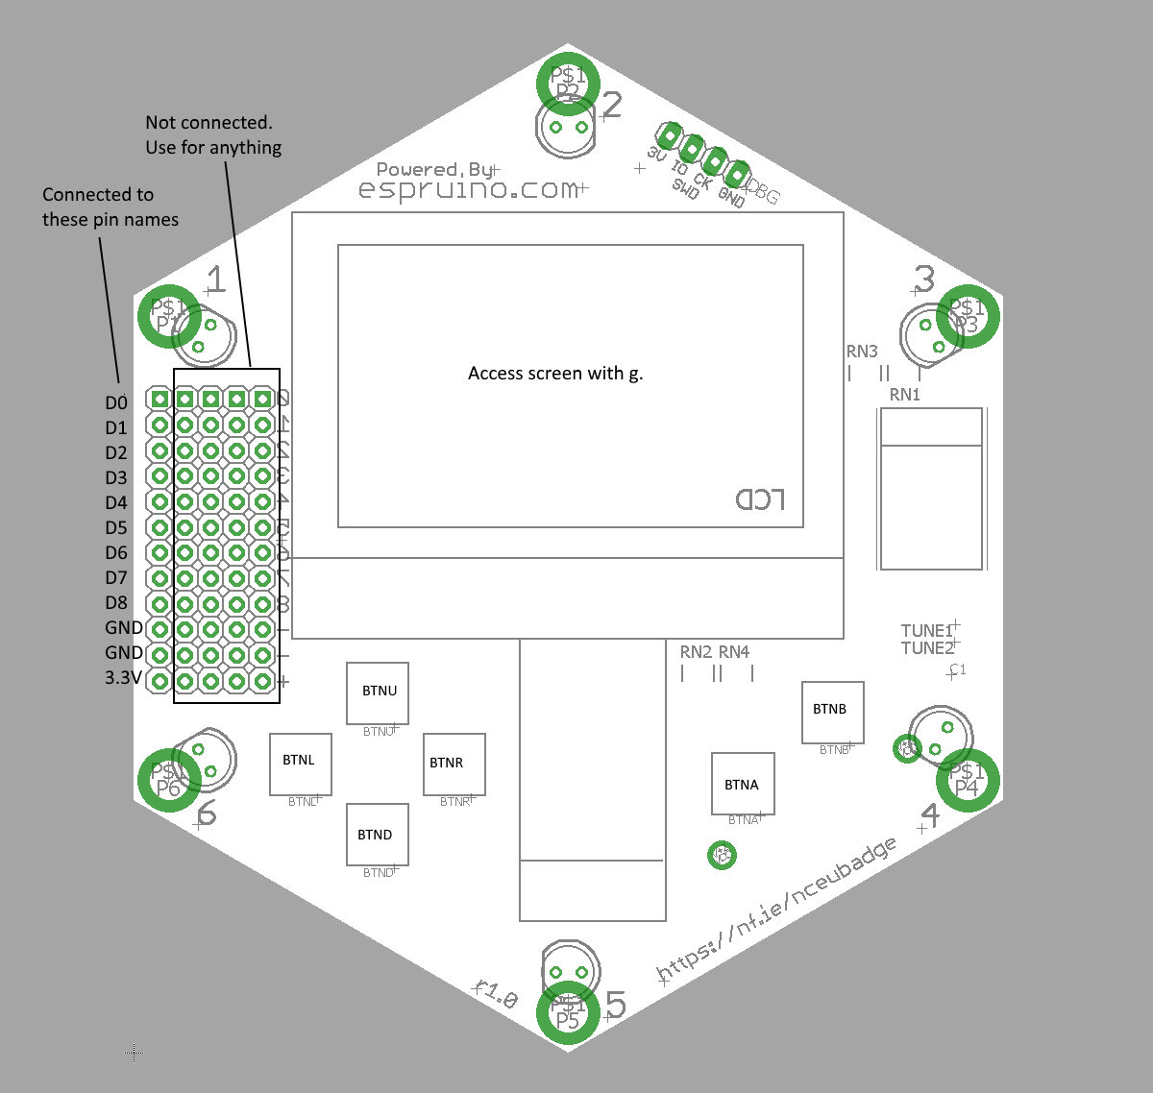
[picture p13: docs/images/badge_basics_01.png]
Board basics


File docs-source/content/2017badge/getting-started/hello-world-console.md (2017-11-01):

---
title: "Hello World on the Console"
weight: 6
date: 2017-10-28T15:30:33+01:00
draft: false
---

Of course we start with Hello World. Follow the [connection instructions](/getting-started/connecting-to-the-badge/), then click on the left hand side of the IDE and type:

```
console.log("Hello World");
```

Now stop and think for a minute about what just happened there in terms of communications flow.

You should try out other aspects of the Web IDE. It has full auto-complete in the REPL window including Button/LED names and functions.

You could also try the built-in Blockly graphical editor which is very similar to Scratch.

Any Espruino code you find here or elsewhere online can be pasted into the editor on the right-hand-side of the IDE and then sent to the badge over Bluetooth for execution. The editor has basic parsing and can flag common errors.

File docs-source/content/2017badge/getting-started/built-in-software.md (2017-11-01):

---
title: "Built-in Software"
weight: 2
date: 2017-10-28T15:30:33+01:00
draft: false
---

Now that you've unlocked the badge (you'll have to do this any time you remove the battery), you can explore the built in sample apps. Out of the box, your badge has the following:

* Your name pre-flashed into the firmware
* Image display cycling
* Selectable menus
* T-Rex who has escaped the Chrome browser
* Flappy Bird
* The world's most awkward on-board REPL
* Etch-a-sketch

Source code for all of these is of course in the [Github Repo](https://github.com/nearform/nceubadge/). More details on these and other samples are [here](/getting-started/other-code-samples/).

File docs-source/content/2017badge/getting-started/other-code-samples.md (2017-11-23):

---
title: "Other Code Samples"
weight: 7
date: 2017-10-28T15:30:33+01:00
draft: false
---

There are three places you can find code to learn from and use:

* The [Badge repo](https://github.com/nearform/nceubadge)
* The [main Espruino site](https://www.espruino.com/)
* The [Puck.js area](https://www.espruino.com/Puck.js) of the Espruino site

## Badge Repo Code
The pre-installed main.js code is a treasure trove of useful snippets. Note however that it's too big to be uploaded in its entirety via the Web IDE.

* [Pre-installed badge code](https://www.espruino.com/ide/#https://raw.githubusercontent.com/nearform/nceubadge/master/flasher/main.js)

### Games
Relive your original Gameboy, Nokia and video arcade days with the following games :-)

* [Flappy Bird](https://www.espruino.com/ide/#https://raw.githubusercontent.com/nearform/nceubadge/master/flappybird.js)
* [Snake](https://www.espruino.com/ide/#https://raw.githubusercontent.com/nearform/nceubadge/master/snake.js)
* [Simple Mario](https://www.espruino.com/ide/#https://raw.githubusercontent.com/nearform/nceubadge/master/mario.js)
* [Asteroids](https://www.espruino.com/ide/#https://raw.githubusercontent.com/nearform/nceubadge/master/asteroids.js)
* [Click speed counter](https://www.espruino.com/ide/#https://raw.githubusercontent.com/nearform/nceubadge/master/click_counter.js)
* [T-Rex](https://www.espruino.com/ide/#https://raw.githubusercontent.com/nearform/nceubadge/master/trex.js)

### Web Bluetooth
* [Retrieve all images stored on a badge](https://github.com/nearform/nceubadge/blob/master/web_bluetooth/badge_images.html) ([try it](/web_bluetooth/badge_images.html))
* [Take a picture with getUserMedia and put it on the badge](https://github.com/nearform/nceubadge/blob/master/web_bluetooth/badge_photo.html) ([try it](/web_bluetooth/badge_photo.html))
* [Upload an image to the badge badge](https://github.com/nearform/nceubadge/blob/master/web_bluetooth/badge_upload.html) ([try it](/web_bluetooth/badge_upload.html))

### Misc
* Check out the [world's most awkward REPL](https://www.espruino.com/ide/#https://raw.githubusercontent.com/nearform/nceubadge/master/repl.js)

* Learn how to [display a Menu](https://www.espruino.com/ide/#https://raw.githubusercontent.com/nearform/nceubadge/master/menu.js)

* Dazzle everyone with your artistic skills on an [Etch-a-sketch](https://www.espruino.com/ide/#https://raw.githubusercontent.com/nearform/nceubadge/master/sketch.js)

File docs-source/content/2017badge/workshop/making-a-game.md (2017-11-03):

---
title: "Making a Game"
weight: 6
date: 2017-11-03T09:45:33+01:00
draft: false
---

Ok, now we'll need to make two functions:

* A function to output a pattern
* A function to check the player's input against a pattern. 

These will take a simple array of numbers, which is the pattern
to output.

## Left -> Right

We've got enough code that we probably want to start using the
right-hand side of the IDE as a proper editor. No changes will take
effect until you press the `Upload` button, but when you upload it'll
blow away any previous changes you made on the left-hand side.

## Outputting a pattern

We've already got the `plotBadge` function from the Graphics section,
as well as `beepForCorner` from the Sound section. All we need to do
is call them at the right times. Copy `plotBadge` and the `beep` stuff onto
the right-hand side, as well as this - and then click the `Upload` button in
the middle of the screen.

```
// Show the given pattern
function showPattern(pattern, callback) {
  // Nothing left - finish
  if (!pattern.length) return callback();  
  // Shift off the first element - don't use shift as
  // that'd alter the initial array  
  var corner = pattern[0];
  pattern = pattern.slice(1);
  // Display a corner and beep
  plotBadge([corner==1, corner==2, corner==3, corner==4, corner==5, corner==6]);
  beepForCorner(corner, 1000);
  // clear screen after a timeout
  setTimeout(function() {    
    g.clear();
    g.flip();
    // go to next
    setTimeout(function() {
      showPattern(pattern, callback);
    }, 200);
  }, 1000);
}

showPattern([1,2,3,4], ()=>console.log("Done!"));
```

## Detecting the pattern

So now you need the following to detect the pattern sequence - it's a 
bit big, but there are comments below:

```
/* Wait for either a corner to be pressed (pressState=true)
or released (pressState=false), and report back what was
pressed in the callback */
function waitForPress(pressState, callback) {
  var intr = setInterval(function() {
    // Detect pressed corners
    var pressed = [1,2,3,4,5,6].map(c=>Badge.capSense(c)>20000);
    // Create a string of only the pressed corners
    pressed = pressed.map((x,i)=>x?i+1:"").join("");
    // Call the callback when something is either pressed or released
    if ((pressed!="") == pressState) {
      clearInterval(intr);
      callback(pressed);
    }
  },20);
}

// Draw big fullscreen, centered text
function plotText(txt) {
  g.clear();
  var size = 32;
  g.setFontVector(size);
  while (g.stringWidth(txt)>120) {
    g.setFontVector(--size);
  }
  g.drawString(txt,(128-g.stringWidth(txt))/2,(64-size)/2);
  g.setFontBitmap();
  g.flip();
}

// Repeatedly test for the correct pattern
function testPattern(pattern, callback) {
  // Nothing left - finish - I guess we passed
  if (!pattern.length) return callback(true);
  // Shift off the first element - don't use shift as
  // that'd alter the initial array  
  var corner = pattern[0];
  pattern = pattern.slice(1);
  // Wait for a press
  plotText("?");  
  waitForPress(true, function(pressedCorner) {
    // check our corner
    if (pressedCorner == corner) {
      plotText(corner);
      beepForCorner(corner, 1000);
      // Great! Next corner, after a delay and
      // the button is released
      setTimeout(function() {
        waitForPress(false, function() {        
          testPattern(pattern, callback);
        });
      }, 1000);
    } else {
      // Game over
      plotText("NO!");
      beep(200, 1000); // low beep
      setTimeout(function() {
        callback(false);
      }, 1000);
    }
  });
}

// Test this out
testPattern([1,2,3,4], x=>console.log("Done!",x));
```

## Sticking it together

So now it's reasonably easy to stick showing the pattern and testing
for the pattern together:

```
var pattern = [5,3,4];
showPattern(pattern, ()=>{
  testPattern(pattern, x=>console.log("Done!",x));
});
```

And finally, you can wrap the whole thing up so that after each successful
pattern it adds one more item to the end:

```
function randomCorner() {
  return 0|Math.min(1+Math.random()*6, 6);
}

function game(pattern) {
  // add a new corner
  pattern.push(randomCorner());
  // Show and test
  console.log("Trying ",pattern);
  showPattern(pattern, ()=>{
    testPattern(pattern, success=>{
      if (success) {
        plotText(":)");
        setTimeout(()=>game(pattern), 1000);
      } else {
        plotText("Game Over");
        // restart when A pressed
        setWatch(function() {
          console.log("Restarting");
          game([]);
        }, BTNA, {repeat:0, debounce:20, edge:"rising"});
      }
    });
  });
}

game([])
```

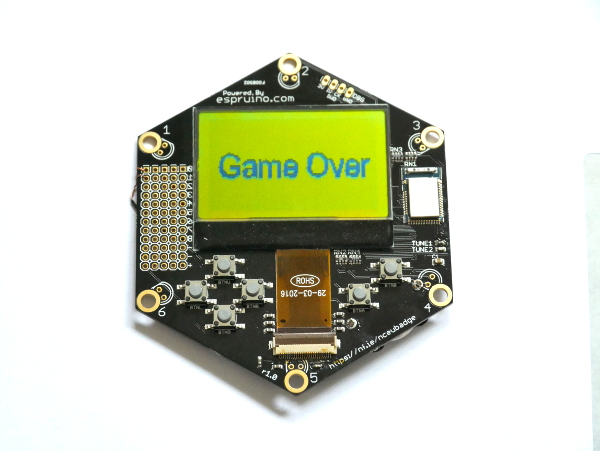
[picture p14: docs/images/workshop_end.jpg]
Game over


## Finally!

And that's it! The finished game should look like this:

```
function plotBadge(presses) {
  g.clear();    
  // function to work out each corner's coordinates
  function corner(c,r) {
    var a = (c-2)*Math.PI/3;
    return [64+Math.sin(a)*40*r, 32-Math.cos(a)*30*r];
  }
  // draw a hexagon - a line to each corner in turn
  g.moveTo.apply(g,corner(6,1));
  [1,2,3,4,5,6].forEach(c=>g.lineTo.apply(g,corner(c,1)));
  // Draw a circle where pressed
  presses.forEach((hit,c) => {
    if (!hit) return;
    var coords = corner(c+1,0.8);
    g.fillCircle(coords[0],coords[1],5);
  });
  g.flip();
}

function beep(freq, time, callback) {
  var ll = require("NRF52LL");
  // set up D0 and D1 as outputs
  digitalWrite(D0,0);
  digitalWrite(D1,0);
  // create two 'toggle' tasks, one for each pin
  var t0 = ll.gpiote(6, {type:"task",pin:D0,lo2hi:1,hi2lo:1,initialState:0});
  var t1 = ll.gpiote(7, {type:"task",pin:D1,lo2hi:1,hi2lo:1,initialState:1});
  // create a timer that counts up to a value depending on the frequency
  var tmr = ll.timer(3,{cc:[500000/freq],cc0clear:1});
  // use two PPI to trigger toggle events
  ll.ppiEnable(6, tmr.eCompare[0], t0.tOut);
  ll.ppiEnable(7, tmr.eCompare[0], t1.tOut);
  // Manually trigger a task to start the timer
  poke32(tmr.tClear,1);
  poke32(tmr.tStart,1);
  setTimeout(function() {
    poke32(tmr.tStop,1);
    ll.ppiDisable(6);
    ll.ppiDisable(7);
    if (callback) callback();
  }, time);
}

function beepForCorner(corner, time) {
  var pitches = ["no_corner_0",
    500,
    600,
    700,
    800,
    900,
    1000
  ];
  beep(pitches[corner], time);
}

// Show the given pattern
function showPattern(pattern, callback) {
  // Nothing left - finish
  if (!pattern.length) return callback();  
  // Shift off the first element - don't use shift as
  // that'd alter the initial array  
  var corner = pattern[0];
  pattern = pattern.slice(1);
  // Display a corner and beep
  plotBadge([corner==1, corner==2, corner==3, corner==4, corner==5, corner==6]);
  beepForCorner(corner, 1000);
  // clear screen after a timeout
  setTimeout(function() {    
    g.clear();
    g.flip();
    // go to next
    setTimeout(function() {
      showPattern(pattern, callback);
    }, 200);
  }, 1000);
}

/* Wait for either a corner to be pressed (pressState=true)
or released (pressState=false), and report back what was
pressed in the callback */
function waitForPress(pressState, callback) {
  var intr = setInterval(function() {
    // Detect pressed corners
    var pressed = [1,2,3,4,5,6].map(c=>Badge.capSense(c)>20000);
    // Create a string of only the pressed corners
    pressed = pressed.map((x,i)=>x?i+1:"").join("");
    // Call the callback when something is either pressed or released
    if ((pressed!="") == pressState) {
      clearInterval(intr);
      callback(pressed);
    }
  },20);
}

// Draw big fullscreen, centered text
function plotText(txt) {
  g.clear();
  var size = 32;
  g.setFontVector(size);
  while (g.stringWidth(txt)>120) {
    g.setFontVector(--size);
  }
  g.drawString(txt,(128-g.stringWidth(txt))/2,(64-size)/2);
  g.setFontBitmap();
  g.flip();
}

// Repeatedly test for the correct pattern
function testPattern(pattern, callback) {
  // Nothing left - finish - I guess we passed
  if (!pattern.length) return callback(true);
  // Shift off the first element - don't use shift as
  // that'd alter the initial array  
  var corner = pattern[0];
  pattern = pattern.slice(1);
  // Wait for a press
  plotText("?");  
  waitForPress(true, function(pressedCorner) {
    // check our corner
    if (pressedCorner == corner) {
      plotText(corner);
      beepForCorner(corner, 1000);
      // Great! Next corner, after a delay and
      // the button is released
      setTimeout(function() {
        waitForPress(false, function() {        
          testPattern(pattern, callback);
        });
      }, 1000);
    } else {
      // Game over
      plotText("NO!");
      beep(200, 1000); // low beep
      setTimeout(function() {
        callback(false);
      }, 1000);
    }
  });
}

function randomCorner() {
  return 0|Math.min(1+Math.random()*6, 6);
}

function game(pattern) {
  // add a new corner
  pattern.push(randomCorner());
  // Show and test
  console.log("Trying ",pattern);
  showPattern(pattern, ()=>{
    testPattern(pattern, success=>{
      if (success) {
        plotText(":)");
        setTimeout(()=>game(pattern), 1000);
      } else {
        plotText("Game Over");
        // restart when A pressed
        setWatch(function() {
          console.log("Restarting");
          game([]);
        }, BTNA, {repeat:0, debounce:20, edge:"rising"});
      }
    });
  });
}

game([])
```

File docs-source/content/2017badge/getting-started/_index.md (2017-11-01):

---
title: "Getting Started"
weight: 1
chapter: true
date: 2017-10-24T15:29:15+01:00
draft: false
---
### Chapter 1

# Getting Started

Lets get you setup with accessing the secret menus, connecting to your badge over Bluetooth and getting Hello World running.

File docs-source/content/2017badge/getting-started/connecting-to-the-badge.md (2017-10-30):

---
title: "Connecting to the Badge"
weight: 5
date: 2017-10-28T15:30:33+01:00
draft: false
---

Any modern computer with Bluetooth 4+ should be able to connect to the badge as follows:

## Make your badge connectable

* Enter the Konami code, if you haven't already: Up, Up, Down, Down, Left, Right, Left, Right, B, A.
* Select "Make badge connectable" in the menu
* Note the Badge ID

## Mac
Web Bluetooth on Chrome should just work if your Chrome is up to date. So simply go to the [Web IDE here](https://www.espruino.com/ide/). Then:

* Click the connect icon in the top left corner
* Select the Web Bluetooth option
* If more than one badge is listed, select your badge ID
* Click Pair
* A few seconds later you'll have a REPL running and you can run JS directly on your badge over Bluetooth!

## Windows
The easiest option is to install the standalone Electron-based Espruino IDE. Download it [from here](https://www.espruino.com/Web+IDE#as-a-native-application)

* If your're using Windows 8.1, or 10 you'll need to pair your Badge using the Windows Bluetooth menu before it'll appear in the Web IDE.
* (Any time you remove the badge battery, you'll have to remove the Badge from the list of paired devices in Windows and re-pair)
* Run the IDE
* Click the connect icon in the top left corner
* Select the Web Bluetooth option
* If more than one badge is listed, select your badge ID
* Click Pair
* A few seconds later you'll have a REPL running and you can run JS directly on your badge over Bluetooth!

## Linux / iOS / Android
* See instructions [here](https://www.espruino.com/Puck.js+Quick+Start)

More setup (and general) information is available on the [Puck.js site](https://www.espruino.com/Puck.js) if you get stuck. Most, but not all, of the information applies to the badge.

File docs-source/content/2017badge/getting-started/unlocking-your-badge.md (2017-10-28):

---
title: "Unlocking Your Badge"
weight: 1
date: 2017-10-24T15:30:33+01:00
draft: false
---

There's a lot more to your badge's software than you realise. Try this:

* Up
* Up
* Down
* Down
* Left
* Right
* Left
* Right
* B
* A

(Yup the Konami code!)

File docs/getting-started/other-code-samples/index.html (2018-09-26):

> Getting Started > Other Code Samples

# Other Code Samples

There are three places you can find code to learn from and use:

- The Badge repo (https://github.com/nearform/nceubadge)
- The main Espruino site (https://www.espruino.com/)
- The Puck.js area (https://www.espruino.com/Puck.js) of the Espruino site

## Badge Repo Code

The pre-installed main.js code is a treasure trove of useful snippets. Note however that it’s too big to be uploaded in its entirety via the Web IDE.

- Pre-installed badge code (https://www.espruino.com/ide/)

### Games

Relive your original Gameboy, Nokia and video arcade days with the following games :-)

- Flappy Bird (https://www.espruino.com/ide/)
- Snake (https://www.espruino.com/ide/#https://raw.githubusercontent.com/nearform/nceubadge/master/snake.js)
- Simple Mario (https://www.espruino.com/ide/#https://raw.githubusercontent.com/nearform/nceubadge/master/mario.js)
- Asteroids (https://www.espruino.com/ide/)
- Click speed counter (https://www.espruino.com/ide/)
- T-Rex (https://www.espruino.com/ide/#https://raw.githubusercontent.com/nearform/nceubadge/master/trex.js)

### Web Bluetooth

- Retrieve all images stored on a badge (https://github.com/nearform/nceubadge/blob/master/web_bluetooth/badge_images.html) (try it)
- Take a picture with getUserMedia and put it on the badge (https://github.com/nearform/nceubadge/blob/master/web_bluetooth/badge_photo.html) (try it)
- Upload an image to the badge badge (https://github.com/nearform/nceubadge/blob/master/web_bluetooth/badge_upload.html) (try it)

### Misc

- Check out the world’s most awkward REPL (https://www.espruino.com/ide/#https://raw.githubusercontent.com/nearform/nceubadge/master/repl.js)
- Learn how to display a Menu (https://www.espruino.com/ide/#https://raw.githubusercontent.com/nearform/nceubadge/master/menu.js)
- Dazzle everyone with your artistic skills on an Etch-a-sketch (https://www.espruino.com/ide/#https://raw.githubusercontent.com/nearform/nceubadge/master/sketch.js)

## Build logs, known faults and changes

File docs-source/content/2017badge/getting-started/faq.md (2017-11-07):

---
title: "FAQ"
weight: 10
date: 2017-11-07T11:30:33+01:00
draft: false
---

What follows are a few answers to common questions we've been asked at the conference:

## Fixing your badge

After uploading code, your badge might not work any more or might show the 'Espruino' logo.

To fix it, just disconnect and reconnect the battery. You can do that by pulling the edge of the battery away from the PCB using a finger nail.

If that doesn't fix the badge, you might need to go to the hacking bench and use the flashing tool there to rewrite the badge's JS firmware.

You can also disconect/reconnect the battery while holding BTNA *until the Espruino logo appears* to make the badge start up without loading any new code. It'll be connectable, but will be completely blank. 

## Saving your code

Espruino can save code in 2 ways - as raw JavaScript, or as a compressed 'RAM image' which is a bit like 'hibernate' - that's the default if you type `save()` (normally any code you upload goes straight into RAM).

Your main badge firmware is stored as raw JS, and there's not enough room to store that as well as saving anything else.

The easiest solution is to just turn on `Save On Send` on in the IDE's options - this switches to saving raw JS to the device's flash whenever you upload - the next upload will remove the badge's existing JavaScript.

If you want to use `save()` - the hibernate style of saving - just remove your badge's built-in JS firmware with `E.setBootCode()`. `save()` will then work great.

## Fixing your badge after the conference

We crammed as much JS code into the badge as we could, but that means that the original [main.js](https://github.com/nearform/nceubadge/blob/master/flasher/main.js) file can't be written using the normal IDE.

You have two options:

* Strip some code out of main.js, and write it with `Save on Send` set in the IDE's settings
* Use [flash_as_js.sh](https://github.com/nearform/nceubadge/blob/master/flasher/flash_as_js.sh) to turn the  badge firmware *into a large JavaScript file that writes directly into flash memory*. This is super nasty and slow - but it will restore your badge to default

## Graphics

You can draw to the display with `g.drawString/etc`, but it won't update immediately - you need to call `g.flip()` to send the contents of the offscreen buffer to the screen whenever you want an update.

### Images

The badge display is 128x64, 1 bit per pixel. All the images for the Badge slideshow are stored in a `Badge.badgeImages` variable which you can change.

There's a page here: https://nodeconfeubadge.org/web_bluetooth/badge_upload.html

Which you can use to add your own images to the badge (or just get the source code for a specific image).

## Adding to existing badge firmware

The original firmware is here: [main.js](https://github.com/nearform/nceubadge/blob/master/flasher/main.js)

Most functionality is stored in a `Badge` variable - you can overwrite/modify any part of it.

In the IDE, make sure `Settings → Communications → Reset Before Send` (and `Save on Send`) is UNCHECKED. You can then upload code from the right-hand side of the IDE without removing any of the badge's existing firmware.

For instance you can replace the 'Badge mode' by copying `Badge.badge` out of `main.js` and modifying it so that you no longer need to enter the Konami code (just the `B`) to get to the menu:

```
Badge.badge = () => {
 Badge.reset();
 var counter = 0;
 var timeout;
 function draw(n) {
  counter += n ? n : 0;
  if (counter < 0) counter = Badge.badgeImages.length - 1;
  if (counter >= Badge.badgeImages.length) counter = 0;
  g.clear();
  g.drawImage(Badge.badgeImages[counter]);
  g.flip();
  var delay = (counter==0) ? 20000 : 2500;
  if (timeout) clearTimeout(timeout);  
  timeout = setTimeout(e => { timeout = undefined; draw(1) }, delay);
 }
 draw(0);
 setWatch(e => Badge.menu(), BTNB, { repeat: 1, debounce: 50, edge: "rising" });
 setWatch(e => { draw(-1); k("U") }, BTNU, { repeat: 1, debounce: 50, edge: "rising" });
 setWatch(e => { draw(1); k("D") }, BTND, { repeat: 1, debounce: 50, edge: "rising" });
}
```

## Using Time

The badge has a Real-time clock, so it can keep track of the current time. You just need to set it.

* You can turn on `Settings → Communications → Set Current Time` in the IDE, and the next upload will set the clock.
* If you're using the `Puck.js` Web Bluetooth library you can also use `Puck.setTime()`. **You can do this by going to any of the example pages, entering the developer console, and typing `Puck.setTime()`**

Once that's done, `new Date()` will give you a `Date` object that you can use to get the current time.

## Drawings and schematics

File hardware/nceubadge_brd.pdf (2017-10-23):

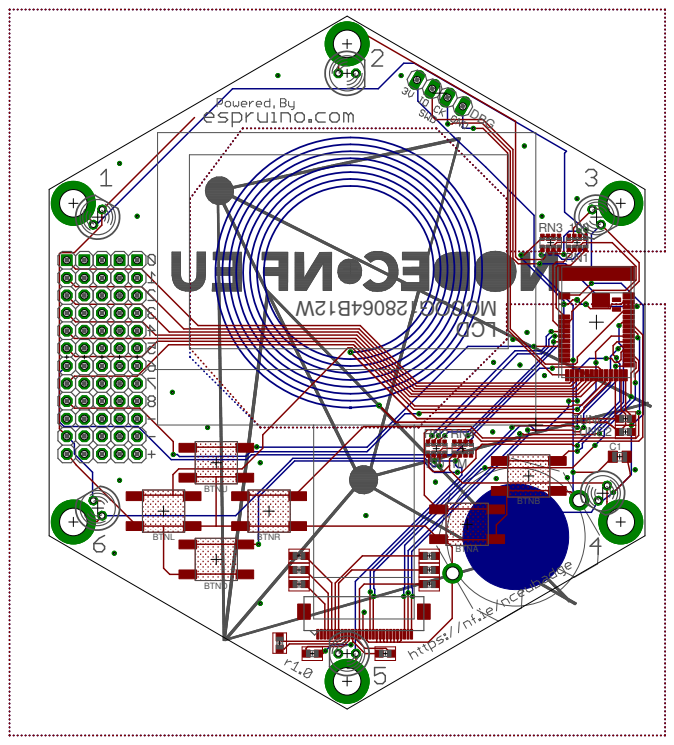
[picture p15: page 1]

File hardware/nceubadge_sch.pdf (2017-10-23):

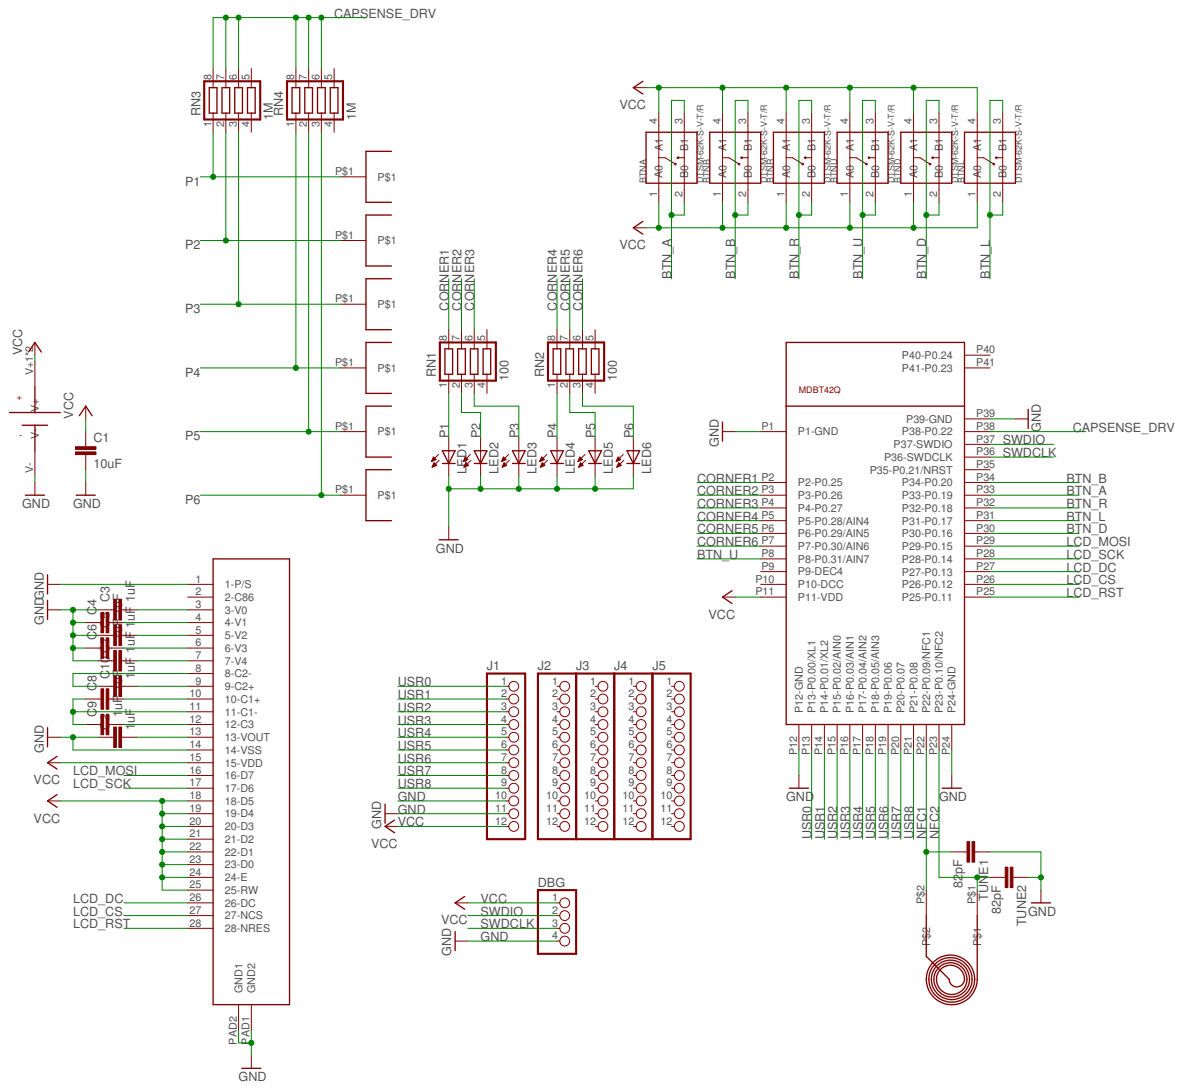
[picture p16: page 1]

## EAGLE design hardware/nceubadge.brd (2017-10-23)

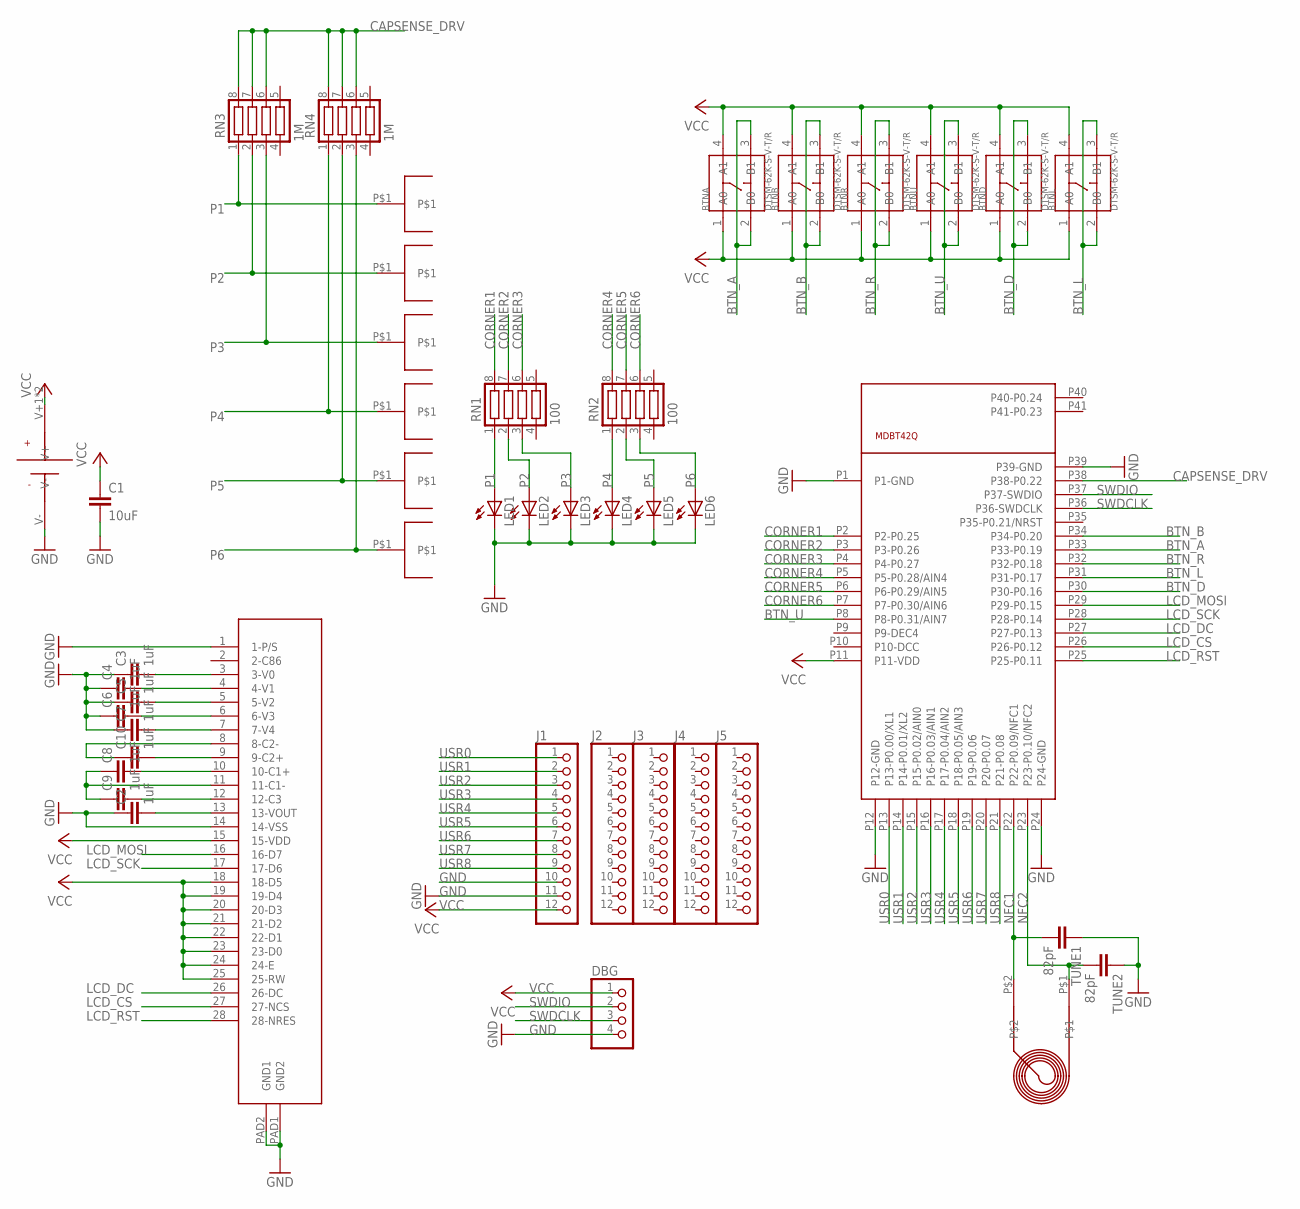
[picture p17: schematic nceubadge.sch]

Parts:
BTNA: DTSM-62K-S-V-T/R; SW4-SMD-6.0X6.0X5.0MM
BTNB: DTSM-62K-S-V-T/R; SW4-SMD-6.0X6.0X5.0MM
BTND: DTSM-62K-S-V-T/R; SW4-SMD-6.0X6.0X5.0MM
BTNL: DTSM-62K-S-V-T/R; SW4-SMD-6.0X6.0X5.0MM
BTNR: DTSM-62K-S-V-T/R; SW4-SMD-6.0X6.0X5.0MM
BTNU: DTSM-62K-S-V-T/R; SW4-SMD-6.0X6.0X5.0MM
C1: 10uF; C0805K
C2, C3, C4, C5, C6, C7, C8, C9, C10: 1uF; C0603
DBG: PINHD-1X4; 1X04
J1, J2, J3, J4, J5: PINHD-1X12_2.54-S; 1X12-S
J8: KEYSTONE-3003
LCD: MCCOG128064B12W; MCOG128064B12W-SPR
LED1, LED2, LED3, LED4, LED5, LED6: LED5MM
RN1, RN2: 100; CTS742C083
RN3, RN4: 1M; CTS742C083
TUNE1, TUNE2: 82pF; C0603
U1: MDBT42Q; MDBT40
U$2, U$3, U$4, U$5, U$6, U$7: BANANAPLUG
U$8: NFC

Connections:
BTN_A: BTNA.2 (B0), BTNA.3 (B1), U1.P33 (P33-P0.19)
BTN_B: BTNB.2 (B0), BTNB.3 (B1), U1.P34 (P34-P0.20)
BTN_D: BTND.2 (B0), BTND.3 (B1), U1.P30 (P30-P0.16)
BTN_L: BTNL.2 (B0), BTNL.3 (B1), U1.P31 (P31-P0.17)
BTN_R: BTNR.2 (B0), BTNR.3 (B1), U1.P32 (P32-P0.18)
BTN_U: BTNU.2 (B0), BTNU.3 (B1), U1.P8 (P8-P0.31/AIN7)
CAPSENSE_DRV: RN3.6, RN3.7, RN3.8, RN4.6, RN4.7, RN4.8, U1.P38 (P38-P0.22)
CORNER1: RN1.8, U1.P2 (P2-P0.25)
CORNER2: RN1.7, U1.P3 (P3-P0.26)
CORNER3: RN1.6, U1.P4 (P4-P0.27)
CORNER4: RN2.8, U1.P5 (P5-P0.28/AIN4)
CORNER5: RN2.7, U1.P6 (P6-P0.29/AIN5)
CORNER6: RN2.6, U1.P7 (P7-P0.30/AIN6)
GND: C1.2, C2.1, C3.1, C4.1, C5.1, C6.1, C7.1, DBG.4, J1.10, J1.11, J8.V-, LCD.1 (1-P/S), LCD.14 (14-VSS), LCD.PAD1 (GND2), LCD.PAD2 (GND1), LED1.K (C), LED2.K (C), LED3.K (C), LED4.K (C), LED5.K (C), LED6.K (C), TUNE1.1, TUNE2.1, U1.P1 (P1-GND), U1.P12 (P12-GND), U1.P24 (P24-GND), U1.P39 (P39-GND)
LCD_CS: LCD.27 (27-NCS), U1.P26 (P26-P0.12)
LCD_DC: LCD.26 (26-DC), U1.P27 (P27-P0.13)
LCD_MOSI: LCD.16 (16-D7), U1.P29 (P29-P0.15)
LCD_RST: LCD.28 (28-NRES), U1.P25 (P25-P0.11)
LCD_SCK: LCD.17 (17-D6), U1.P28 (P28-P0.14)
unnamed: C8.1, C9.1, LCD.11 (11-C1-)
unnamed: C8.2, LCD.10 (10-C1+)
unnamed: C9.2, LCD.12 (12-C3)
unnamed: C2.2, LCD.13 (13-VOUT)
unnamed: C7.2, LCD.7 (7-V4)
unnamed: C6.2, LCD.6 (6-V3)
unnamed: C5.2, LCD.5 (5-V2)
unnamed: C4.2, LCD.4 (4-V1)
unnamed: C3.2, LCD.3 (3-V0)
unnamed: C10.2, LCD.9 (9-C2+)
unnamed: C10.1, LCD.8 (8-C2-)
NFC1: TUNE1.2, U1.P22 (P22-P0.09/NFC1), U$8.P$2
NFC2: TUNE2.2, U1.P23 (P23-P0.10/NFC2), U$8.P$1
P1: LED1.A, RN1.1, RN3.1, U$6.P$1
P2: LED2.A, RN1.2, RN3.2, U$7.P$1
P3: LED3.A, RN1.3, RN3.3, U$5.P$1
P4: LED4.A, RN2.1, RN4.1, U$4.P$1
P5: LED5.A, RN2.2, RN4.2, U$3.P$1
P6: LED6.A, RN2.3, RN4.3, U$2.P$1
SWDCLK: DBG.3, U1.P36 (P36-SWDCLK)
SWDIO: DBG.2, U1.P37 (P37-SWDIO)
USR0: J1.1, U1.P13 (P13-P0.00/XL1)
USR1: J1.2, U1.P14 (P14-P0.01/XL2)
USR2: J1.3, U1.P15 (P15-P0.02/AIN0)
USR3: J1.4, U1.P16 (P16-P0.03/AIN1)
USR4: J1.5, U1.P17 (P17-P0.04/AIN2)
USR5: J1.6, U1.P18 (P18-P0.05/AIN3)
USR6: J1.7, U1.P19 (P19-P0.06)
USR7: J1.8, U1.P20 (P20-P0.07)
USR8: J1.9, U1.P21 (P21-P0.08)
VCC: BTNA.1 (A0), BTNA.4 (A1), BTNB.1 (A0), BTNB.4 (A1), BTND.1 (A0), BTND.4 (A1), BTNL.1 (A0), BTNL.4 (A1), BTNR.1 (A0), BTNR.4 (A1), BTNU.1 (A0), BTNU.4 (A1), C1.1, DBG.1, J1.12, J8.V+1 (V+), J8.V+2 (V+), LCD.15 (15-VDD), LCD.18 (18-D5), LCD.19 (19-D4), LCD.20 (20-D3), LCD.21 (21-D2), LCD.22 (22-D1), LCD.23 (23-D0), LCD.24 (24-E), LCD.25 (25-RW), U1.P11 (P11-VDD)

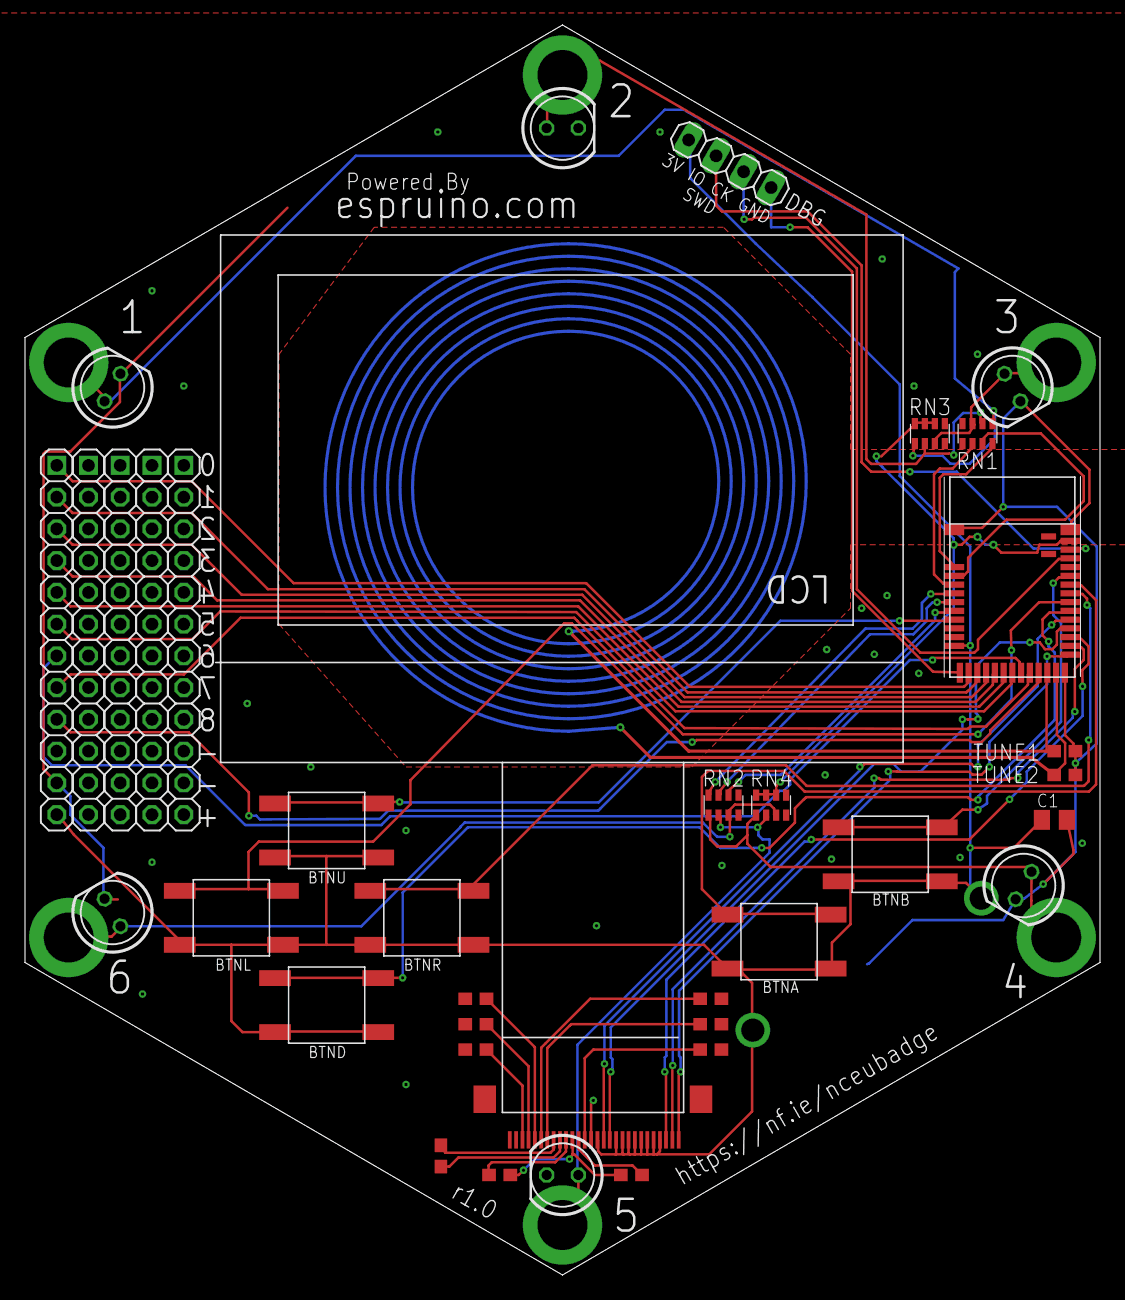
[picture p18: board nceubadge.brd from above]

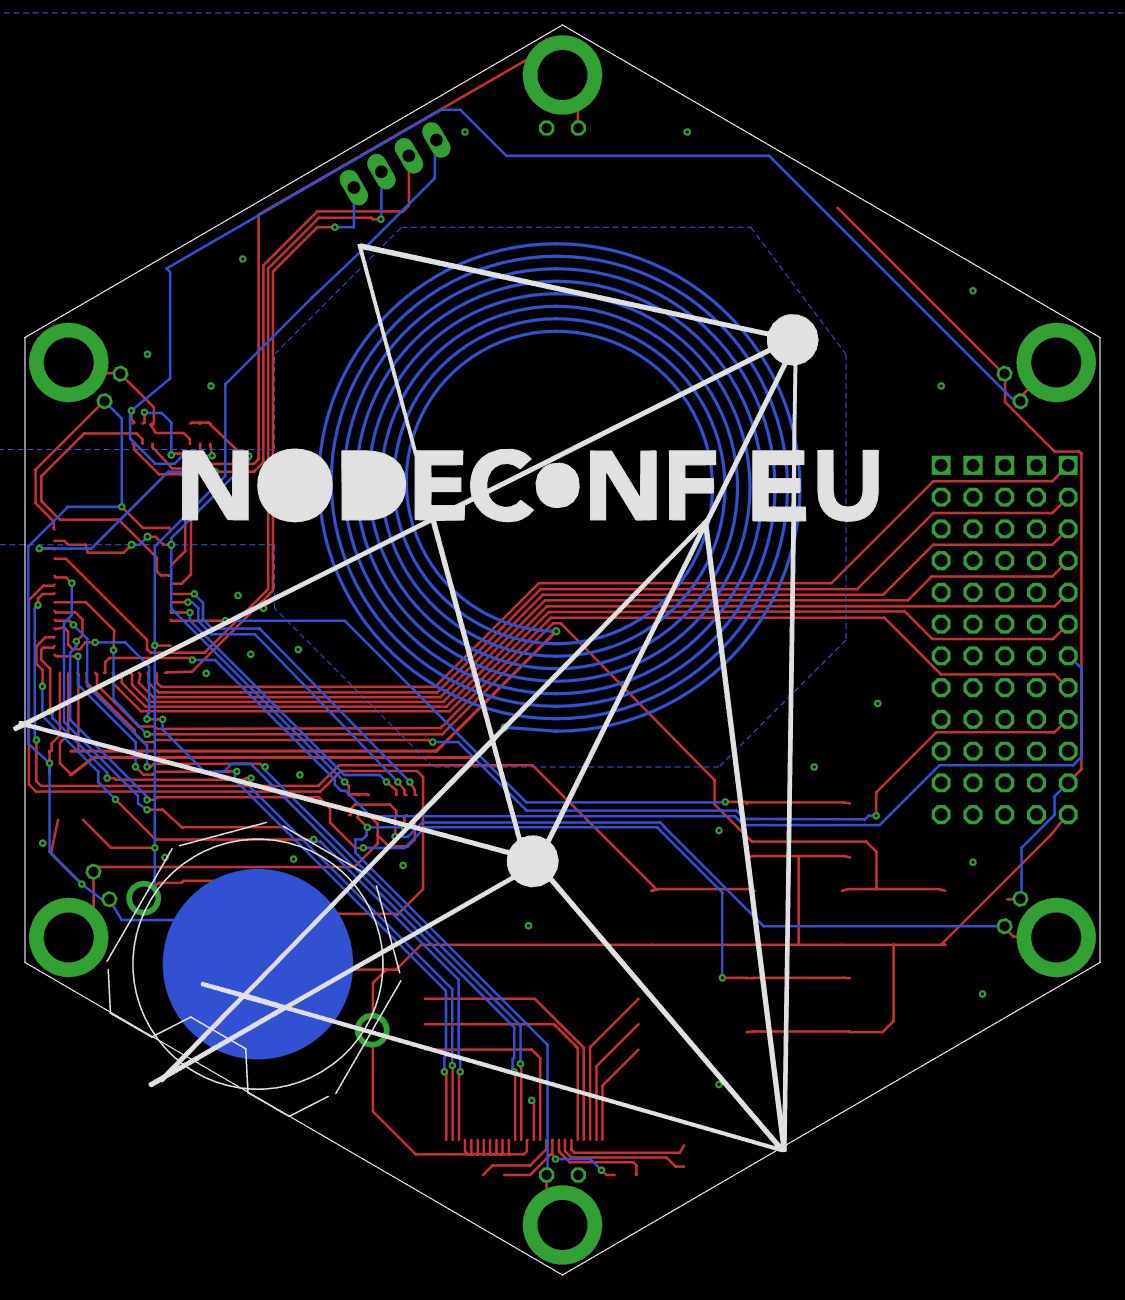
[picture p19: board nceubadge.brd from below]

Board: 2 copper layers, 86.0 x 100.0 mm, 44 parts (2 on the bottom side), 50 nets.

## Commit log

2017-10-24 robots.txt just in case
2017-10-24 robots.txt just in case again
2017-10-24 Added outstanding To-Dos and user flow to repo README
2017-10-25 New text layout tested on multiple names. Seems fine. Switched to Verdana too
2017-10-25 replaced the Fonz with just Hello in case it causes any issues.
2017-10-28 Simplified board image with some comments explaining how to connect things
2017-10-30 Bulk generator of name images and NFC URLs to run in advance of event.
    [name_images_and_urls.csv]
2017-10-30 improved sample data
    [name_images_and_urls.csv]
2017-10-30 make sure real data never committed
    [name_images_and_urls.csv]
2017-11-01 learns how to spell capacitive
2017-11-02 removed sound recording challenge. Added more info about pin capabilities. May need more info there
2017-11-03 de-duplicate titles
